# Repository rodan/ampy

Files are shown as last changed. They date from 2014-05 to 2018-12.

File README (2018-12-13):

an audio amplifier project that contains a mixer controlled by an MSP430 microcontroller

contents:
 hardware/power_amp  - power circuit for the amplifier
 hardware/power_pre  - power circuit used by the mixer board
 hardware/amp        - 2x25W amplifier. for a quad setup this board is used twice, for 6 channels it's used 3 times.
 hardware/mixer      - mixer board. 10 inputs, 6 outputs, 12 channels of mixing. a stereo-to-quad panning circuit is included

 firmware_mixer      - software that runs on the MSP430F5510 that is present on the mixer board
 firmware_brain      - software for the main uC (CC430F5137) that interfaces the user with the mixer board. currently user input comes via remote control presses.
 firmware_display    - software that runs on the atmega present on the BADGEr. this is a simple adaptation on Jeremy Blum's "Pi BADGEr ePaper Weather Station".

 linux               - linux client that talks over a serial link to firmware_brain and controls the mixer and the power amp

pictures now available: https://photos.app.goo.gl/L8txqSKrcZFV2BbR8

--------------------------------------------

Mixer board input

two different input methods are available, either via UART or I2C. since they use the exact same 2 pins the switch between them is a compile time option - see config.h. the i2c interface is highly recommended.

I2C implementation

the communication protocol consists of either a direct 14 byte read in which case the current settings are being shared, 2 byte writes for sending commands or 4 byte writes for sending new volume values. the slave address is 0x28.

UART commands
v___   set volume
 ||+ volume - [0-255]
 |+- channel - {r,l,b}
 +-- pga ID - [1-6]
     1: front, 2: rear, 3: line-in
     4: spdif, 5: front-rear pan, 6: center and subwoofer
m_     mute pga
 +- pga ID - [1-6]
u_     unmute pga
 +- pga ID - [1-6]
w_     write current settings to flash
 +- location [1-3]
r_     load saved settings from flash
 +- location [1-3]
s      show settings
?      show help

 homepage:        https://github.com/rodan/ampy
 author:          Petre Rodan <2b4eda@subdimension.ro>
 license:         GNU GPLv3

 parts of the code were originally forked from the openchronos-ng project [1]. 
 linux mixer control code based on alsamixer [2]

 software requirements:

   msp430 toolchain

[1] http://openchronos-ng.sourceforge.net
[2] http://www.alsa-project.org

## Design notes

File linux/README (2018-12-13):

Linux mixer control software for the ampy ecosystem.

Either an FTDI-based USB-to-uart or a USB bluetooth connection that supports SPP is used to connect to firmare_brain in order to control the mixer and the power amp boards.

All the PGA2311 chips present on the mixer board can be set in the [mixer view] and on the [amp view] the sound detection and mute signals can be toggled.
The second only works if the power amp is based on the LM4780 IC.

in order to compile, rnu the following:

./bootstrap
./configure
make

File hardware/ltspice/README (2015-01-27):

LTspice IV ver 4.22q simulations for the mixer board and the sound detection circuit

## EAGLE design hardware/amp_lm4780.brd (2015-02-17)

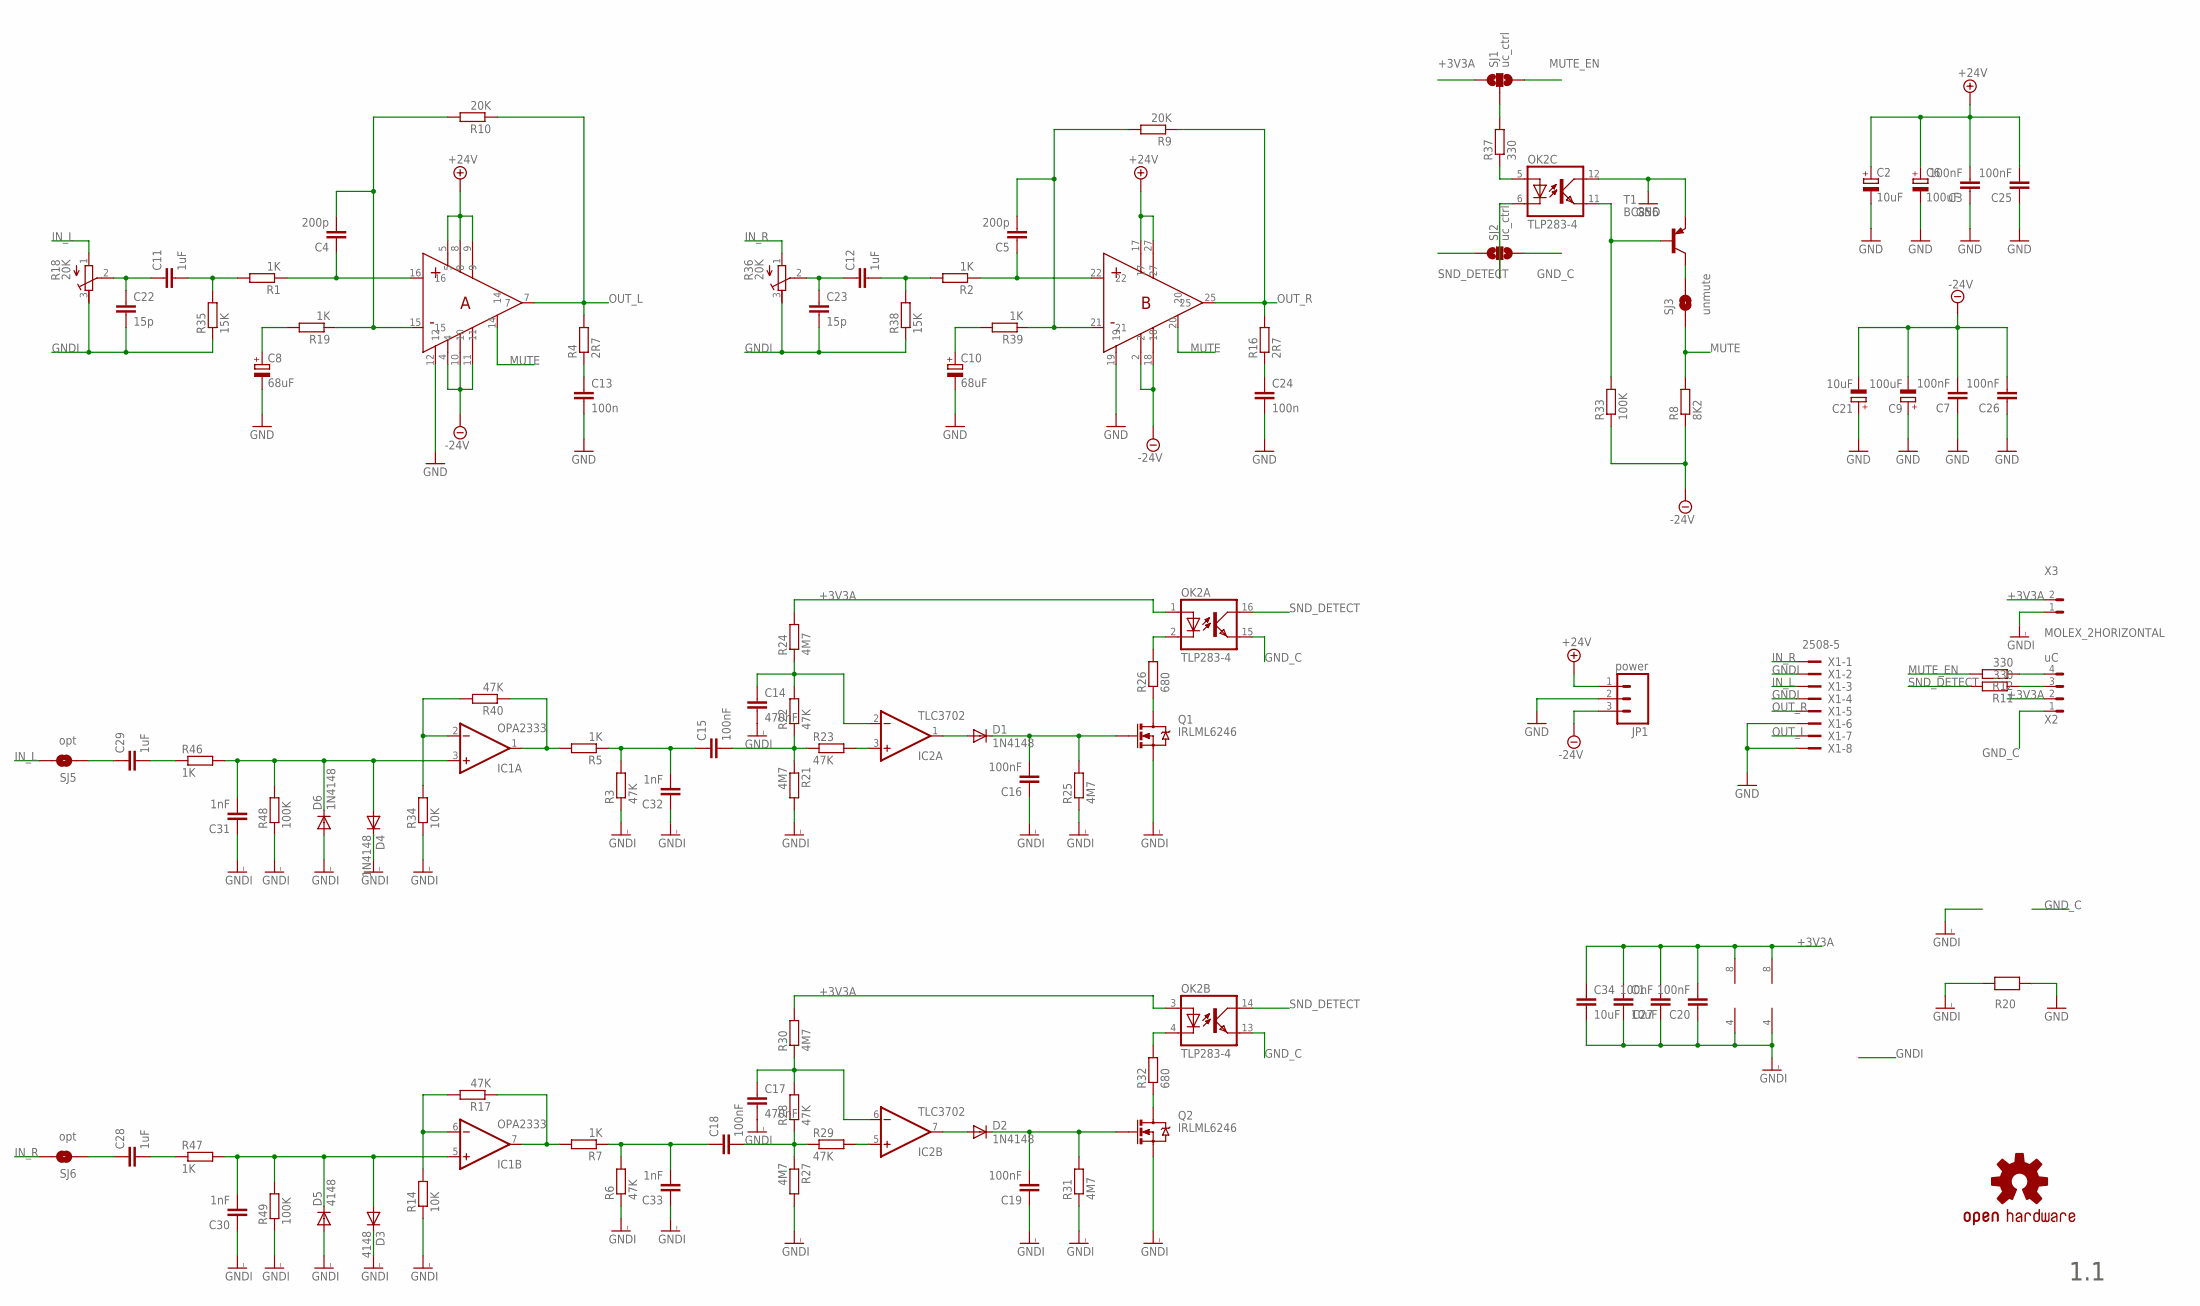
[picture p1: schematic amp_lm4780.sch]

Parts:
C1, C34: 10uF; C1206K
C2, C21: 10uF; PANASONIC_C
C3, C7, C15, C16, C18, C19, C20, C25, C26, C27: 100nF; C0805
C4, C5: 200p; C0805
C6, C9: 100uF; PANASONIC_G
C8, C10: 68uF; PANASONIC_E
C11, C12: 1uF; C050-035X075
C13, C24: 100n; C10B5
C14, C17: 470nF; C0805
C22, C23: 15p; C0805
C28, C29: 1uF; C0805
C30, C31, C32, C33: 1nF; C0805
D1, D2, D4, D6: 1N4148; SOD-123_MINI-SMA
D3, D5: 4148; SOD-123_MINI-SMA
IC1: OPA2333; SO08
IC2: TLC3702; SO08
JP1: power; 1X03
OK2: TLP283-4; MINI-FLAT-16
Q1, Q2: IRLML6246; SOT23-3
R1, R2, R5, R7, R46, R47: 1K; R0805W
R3, R6, R17, R22, R23, R28, R29, R40: 47K; R0805W
R4, R16: 2R7; P0613/15
R8: 8K2; R0805W
R9, R10: 20K; R0805W
R11, R12, R37: 330; R0805W
R14, R34: 10K; R0805W
R18, R36: 20K; RTRIM3339P
R19, R39: 1K; P0613/15
R20: 0R_0805; R0805W
R21, R24, R25, R27, R30, R31: 4M7; R0805W
R26, R32: 680; R0805W
R33, R48, R49: 100K; R0805W
R35, R38: 15K; R0805W
SJ1, SJ2: uc_ctrl; SJ_3_PASTE2&3
SJ3: unmute; SJ_2S-TRACE
SJ5, SJ6: opt; SJ_2S-TRACE
T1: BC856; SOT23-BEC
U$1: LM4780_H; TO220-27_HOR
U$7: OSHW-LOGOM; OSHW-LOGO-M
X1: 2508-5; PAK100/2500-5-08
X2: uC; 0530480401
X3: MOLEX_2HORIZONTAL; 0530480210

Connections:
+3V3A: C1.1, C20.2, C27.2, C34.1, IC1.8 (V+), IC2.8 (V+), OK2.1 (A), OK2.3 (A), R24.2, R30.2, SJ1.1, X2.2 (3), X3.2 (1)
+24V: C2.+, C3.2, C6.+, C25.2, JP1.1, U$1.5, U$1.8, U$1.9, U$1.17, U$1.27
-24V: C7.2, C9.-, C21.-, C26.2, JP1.3, R8.1, R33.1, U$1.2, U$1.4, U$1.10, U$1.11, U$1.18
GND: C2.-, C3.1, C6.-, C7.1, C8.-, C9.+, C10.-, C13.2, C21.+, C24.2, C25.1, C26.1, JP1.2, OK2.12 (COL), R20.2, T1.E, U$1.12, U$1.19, X1.6, X1.8
GNDI: C1.2, C14.2, C16.1, C17.2, C19.1, C20.1, C22.2, C23.2, C27.1, C30.1, C31.1, C32.1, C33.1, C34.2, D3.C, D4.C, D5.A, D6.A, IC1.4 (V-), IC2.4 (V-), Q1.2 (S), Q2.2 (S), R3.1, R6.1, R14.1, R18.3 (E), R20.1, R21.2, R25.1, R27.2, R31.1, R34.1, R35.1, R36.3 (E), R38.1, R48.1, R49.1, X1.2, X1.4, X3.1 (2)
GND_C: OK2.13 (EMIT), OK2.15 (EMIT), SJ2.3, X2.1 (4)
IN_L: R18.1 (A), SJ5.2, X1.3
IN_R: R36.1 (A), SJ6.2, X1.1
MUTE: R8.2, SJ3.1, U$1.14, U$1.20
MUTE_EN: R12.2, SJ1.3
unnamed: C5.2, R9.2, R39.1, U$1.21
unnamed: SJ3.2, T1.C
unnamed: R11.1, X2.3 (2)
unnamed: R12.1, X2.4 (1)
unnamed: IC1.6 (-IN), R14.2, R17.2
unnamed: C13.1, R4.1
unnamed: IC1.7 (OUT), R7.2, R17.1
unnamed: C4.1, R1.1, U$1.16
unnamed: C11.2, R1.2, R35.2
unnamed: C11.1, C22.1, R18.2 (S)
unnamed: C15.2, R21.1, R22.1, R23.1
unnamed: IC1.2 (-IN), R34.2, R40.2
unnamed: IC1.1 (OUT), R5.2, R40.1
unnamed: C24.1, R16.1
unnamed: D1.A, IC2.1 (OUT)
unnamed: C28.1, SJ6.1
unnamed: C30.2, D3.A, D5.C, IC1.5 (+IN), R47.2, R49.2
unnamed: C28.2, R47.1
unnamed: C29.1, SJ5.1
unnamed: IC2.3 (+IN), R23.2
unnamed: OK2.6 (C), SJ2.2
unnamed: Q1.3 (D), R26.1
unnamed: C14.1, IC2.2 (-IN), R22.2, R24.1
unnamed: C29.2, R46.1
unnamed: OK2.2 (C), R26.2
unnamed: C15.1, C32.2, R3.2, R5.1
unnamed: C31.2, D4.A, D6.C, IC1.3 (+IN), R46.2, R48.2
unnamed: C16.2, D1.C, Q1.1 (G), R25.2
unnamed: D2.A, IC2.7 (OUT)
unnamed: R37.2, SJ1.2
unnamed: C17.1, IC2.6 (-IN), R28.2, R30.1
unnamed: C18.2, R27.1, R28.1, R29.1
unnamed: C18.1, C33.2, R6.2, R7.1
unnamed: IC2.5 (+IN), R29.2
unnamed: C19.2, D2.C, Q2.1 (G), R31.2
unnamed: Q2.3 (D), R32.1
unnamed: OK2.4 (C), R32.2
unnamed: OK2.11 (EMIT), R33.2, T1.B
unnamed: C5.1, R2.1, U$1.22
unnamed: OK2.5 (A), R37.1
unnamed: C12.2, R2.2, R38.2
unnamed: C12.1, C23.1, R36.2 (S)
unnamed: C4.2, R10.2, R19.1, U$1.15
unnamed: C8.+, R19.2
unnamed: C10.+, R39.2
OUT_L: R4.2, R10.1, U$1.7, X1.7
OUT_R: R9.1, R16.2, U$1.25, X1.5
SND_DETECT: OK2.14 (COL), OK2.16 (COL), R11.2, SJ2.1

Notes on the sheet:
1.1

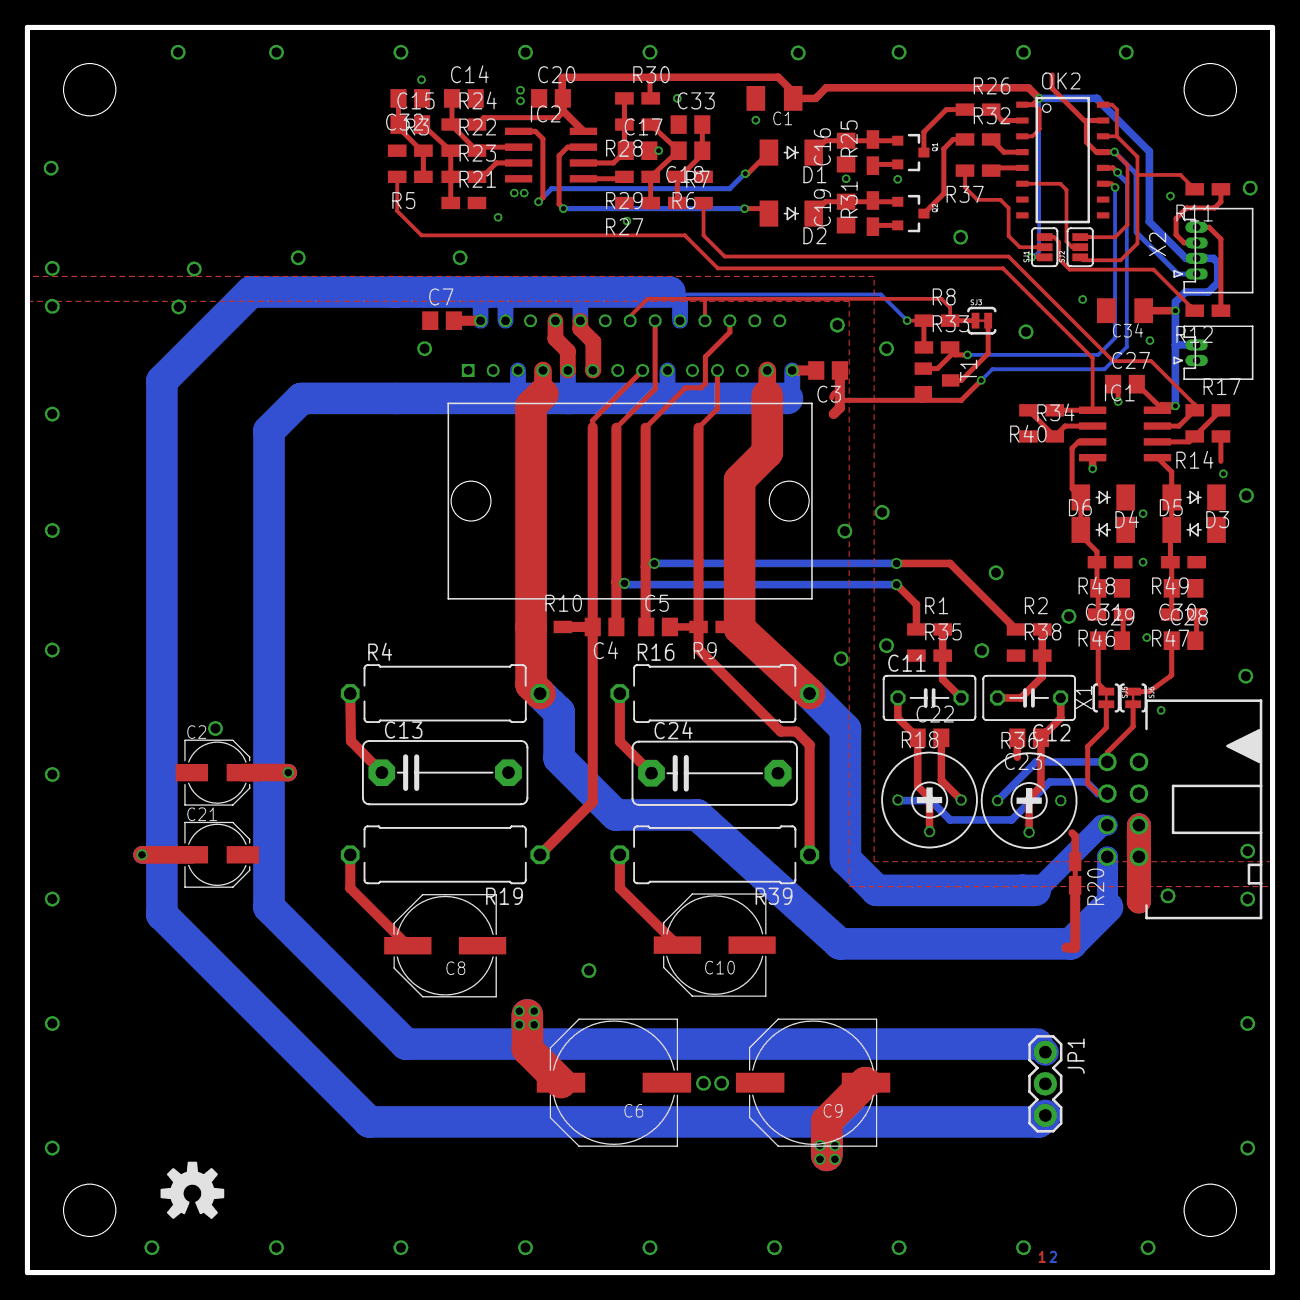
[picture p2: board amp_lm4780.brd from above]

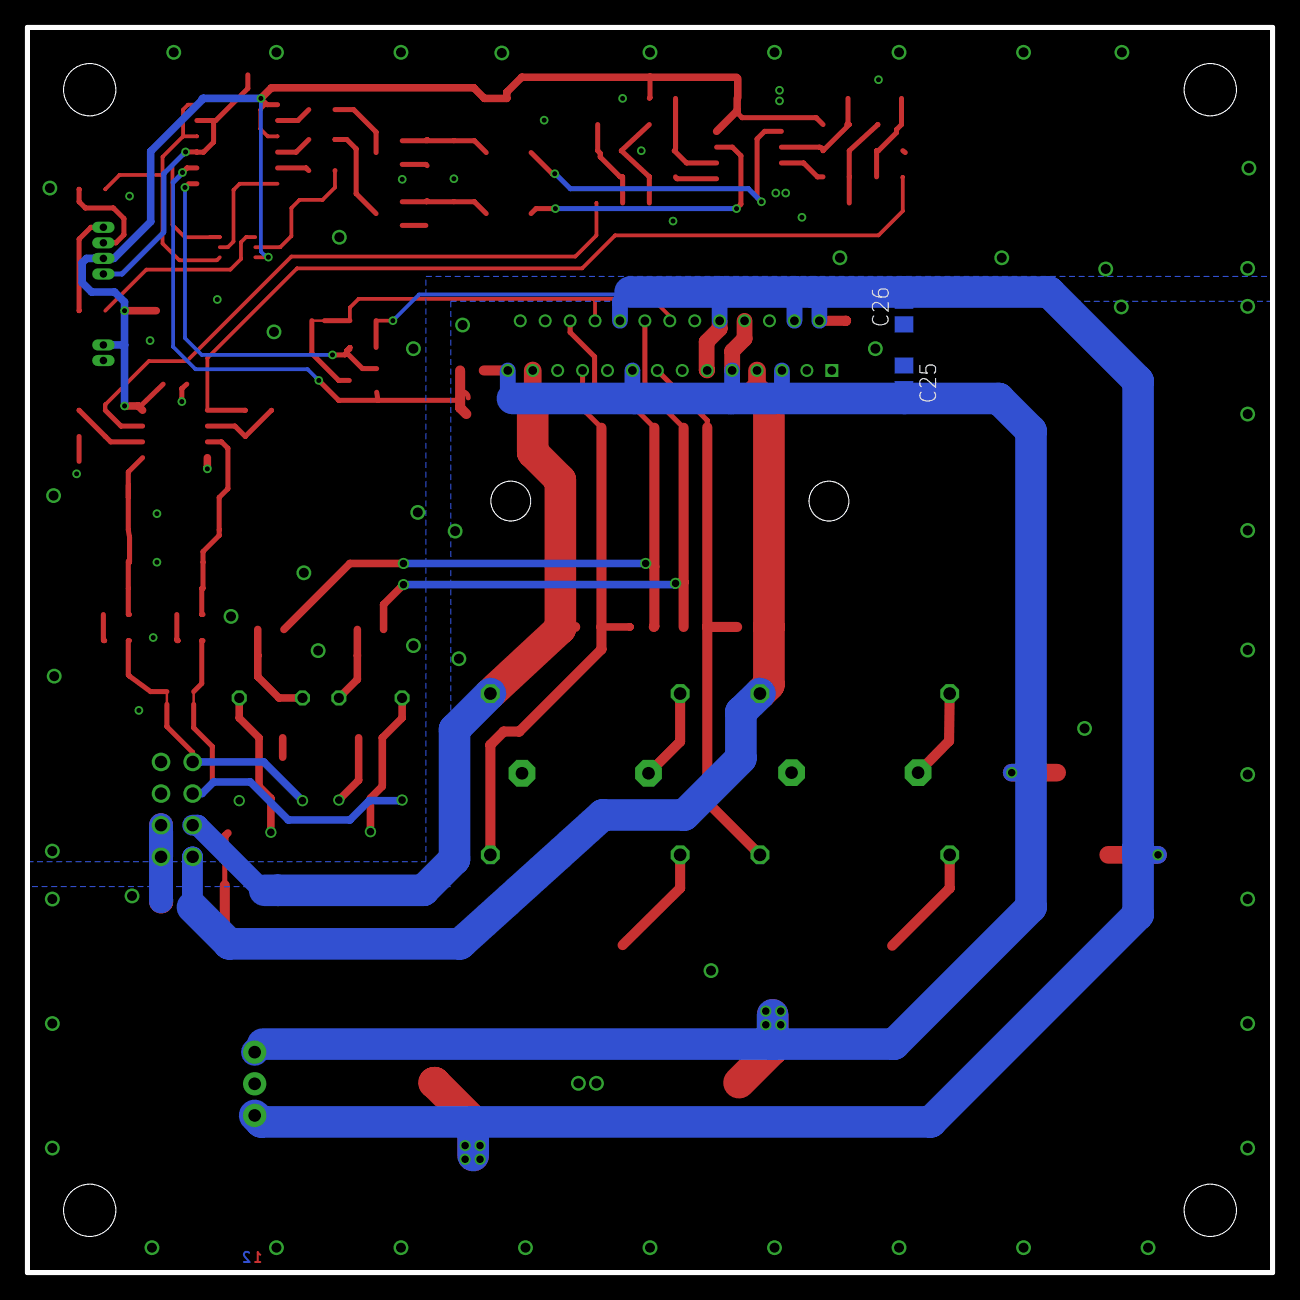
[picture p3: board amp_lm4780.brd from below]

Board: 4 copper layers, 100.0 x 100.0 mm, 99 parts (2 on the bottom side), 58 nets.

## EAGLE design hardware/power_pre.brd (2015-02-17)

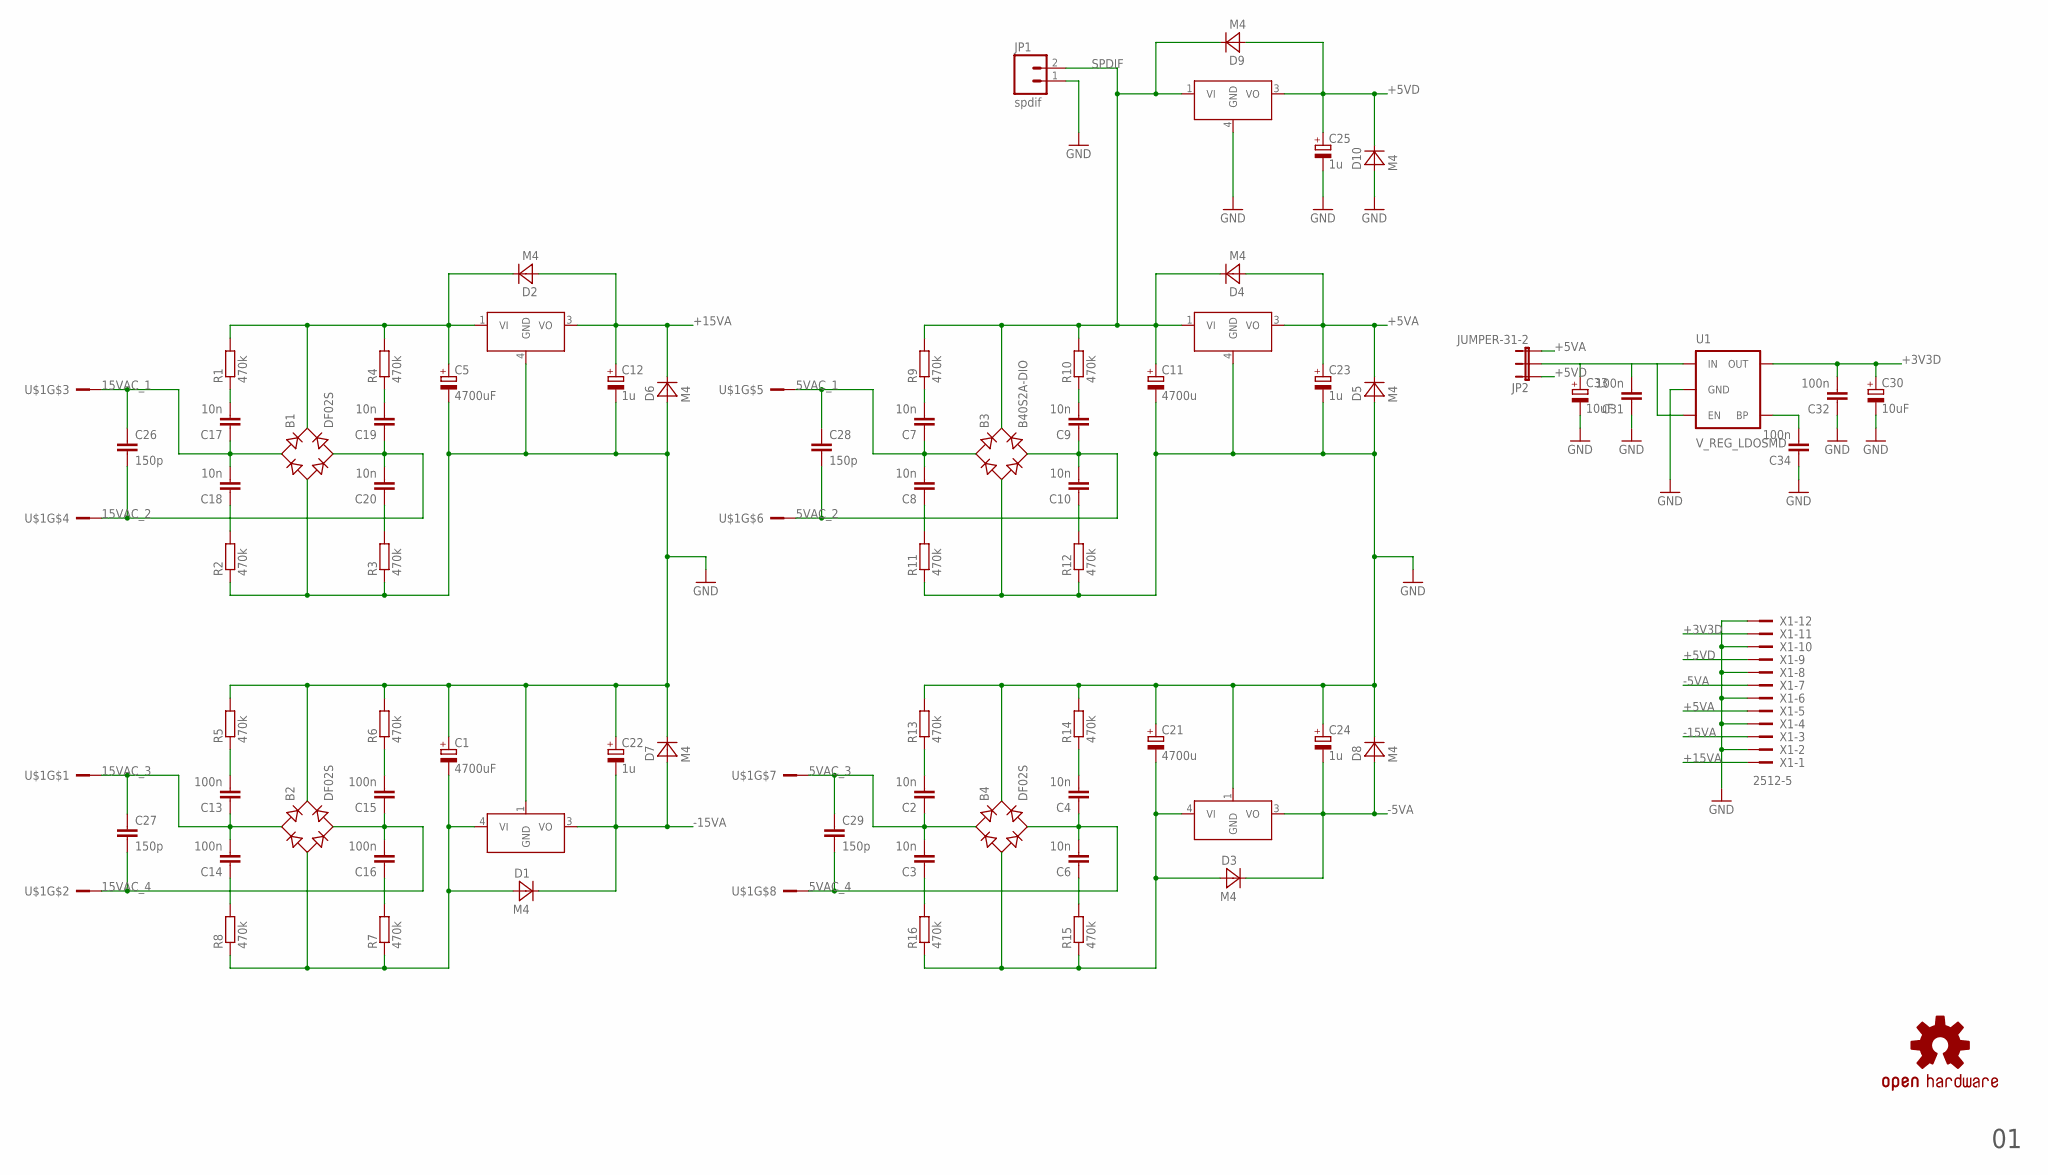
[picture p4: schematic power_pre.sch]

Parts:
B1, B2, B4: DF02S; DFS
B3: B40S2A-DIO; DFS
C1, C5: 4700uF; E7,5-18
C2, C3, C4, C6, C7, C8, C9, C10, C17, C18, C19, C20: 10n; C0805
C11, C21: 4700u; E7,5-16
C12, C22, C23, C24, C25: 1u; PANASONIC_B
C13, C14, C15, C16, C31, C32, C34: 100n; C0805
C26, C27, C28, C29: 150p; C5B4.5
C30, C33: 10uF; 153CLV-0405
D1, D2, D3, D4, D5, D6, D7, D8, D9, D10: M4; SMA
IC1: 7815; D2PACK
IC2: 7915; D2PACK
IC3, IC5: 7805; D2PACK
IC4: 7905; D2PACK
JP1: spdif; 1X02
JP2: JUMPER-31-2; SJ_3_PASTE1&2
R1, R2, R3, R4, R5, R6, R7, R8, R9, R10, R11, R12, R13, R14, R15, R16: 470k; R0805W
U1: V_REG_LDOSMD; SOT23-5
U$1: DEGSON_8
U$7: OSHW-LOGOM; OSHW-LOGO-M
X1: 2512-5; PAK100/2500-5-12

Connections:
5VAC_1: B3.AC1, C7.1, C8.2, C28.1, U$1.5
5VAC_2: B3.AC2, C9.1, C10.2, C28.2, U$1.6
5VAC_3: B4.AC1, C2.1, C3.2, C29.1, U$1.7
5VAC_4: B4.AC2, C4.1, C6.2, C29.2, U$1.8
15VAC_1: B1.AC1, C17.1, C18.2, C26.1, U$1.3
15VAC_2: B1.AC2, C19.1, C20.2, C26.2, U$1.4
15VAC_3: B2.AC1, C13.1, C14.2, C27.1, U$1.1
15VAC_4: B2.AC2, C15.1, C16.2, C27.2, U$1.2
+3V3D: C30.+, C32.2, U1.5 (OUT), X1.11
+5VA: C23.+, D4.A, D5.C, IC3.3 (VO), JP2.3, X1.5
+5VD: C25.+, D9.A, D10.C, IC5.3 (VO), JP2.1, X1.9
+15VA: C12.+, D2.A, D6.C, IC1.3 (VO), X1.1
-5VA: C24.-, D3.C, D8.A, IC4.3 (VO), X1.7
-15VA: C22.-, D1.C, D7.A, IC2.3 (VO), X1.3
GND: B1.-, B2.+, B3.-, B4.+, C1.+, C5.-, C11.-, C12.-, C21.+, C22.+, C23.-, C24.+, C25.-, C30.-, C31.1, C32.1, C33.-, C34.1, D5.A, D6.A, D7.C, D8.C, D10.A, IC1.4 (GND), IC2.1 (GND), IC3.4 (GND), IC4.1 (GND), IC5.4 (GND), JP1.1, R2.1, R3.1, R5.2, R6.2, R11.1, R12.1, R13.2, R14.2, U1.2 (GND), X1.2, X1.4, X1.6, X1.8, X1.10, X1.12
unnamed: C7.2, R9.1
unnamed: C18.1, R2.2
unnamed: C31.2, C33.+, JP2.2, U1.1 (IN), U1.3 (EN)
unnamed: C13.2, R5.1
unnamed: C34.2, U1.4 (BP)
unnamed: B1.+, C5.+, D2.C, IC1.1 (VI), R1.2, R4.2
unnamed: C17.2, R1.1
unnamed: B4.-, C21.-, D3.A, IC4.4 (VI), R15.1, R16.1
unnamed: C19.2, R4.1
unnamed: C20.1, R3.2
unnamed: C6.1, R15.2
unnamed: C8.1, R11.2
unnamed: B2.-, C1.-, D1.A, IC2.4 (VI), R7.1, R8.1
unnamed: C14.1, R8.2
unnamed: C16.1, R7.2
unnamed: C15.2, R6.1
unnamed: C10.1, R12.2
unnamed: C9.2, R10.1
unnamed: C3.1, R16.2
unnamed: C2.2, R13.1
unnamed: C4.2, R14.1
SPDIF: B3.+, C11.+, D4.C, D9.C, IC3.1 (VI), IC5.1 (VI), JP1.2, R9.2, R10.2

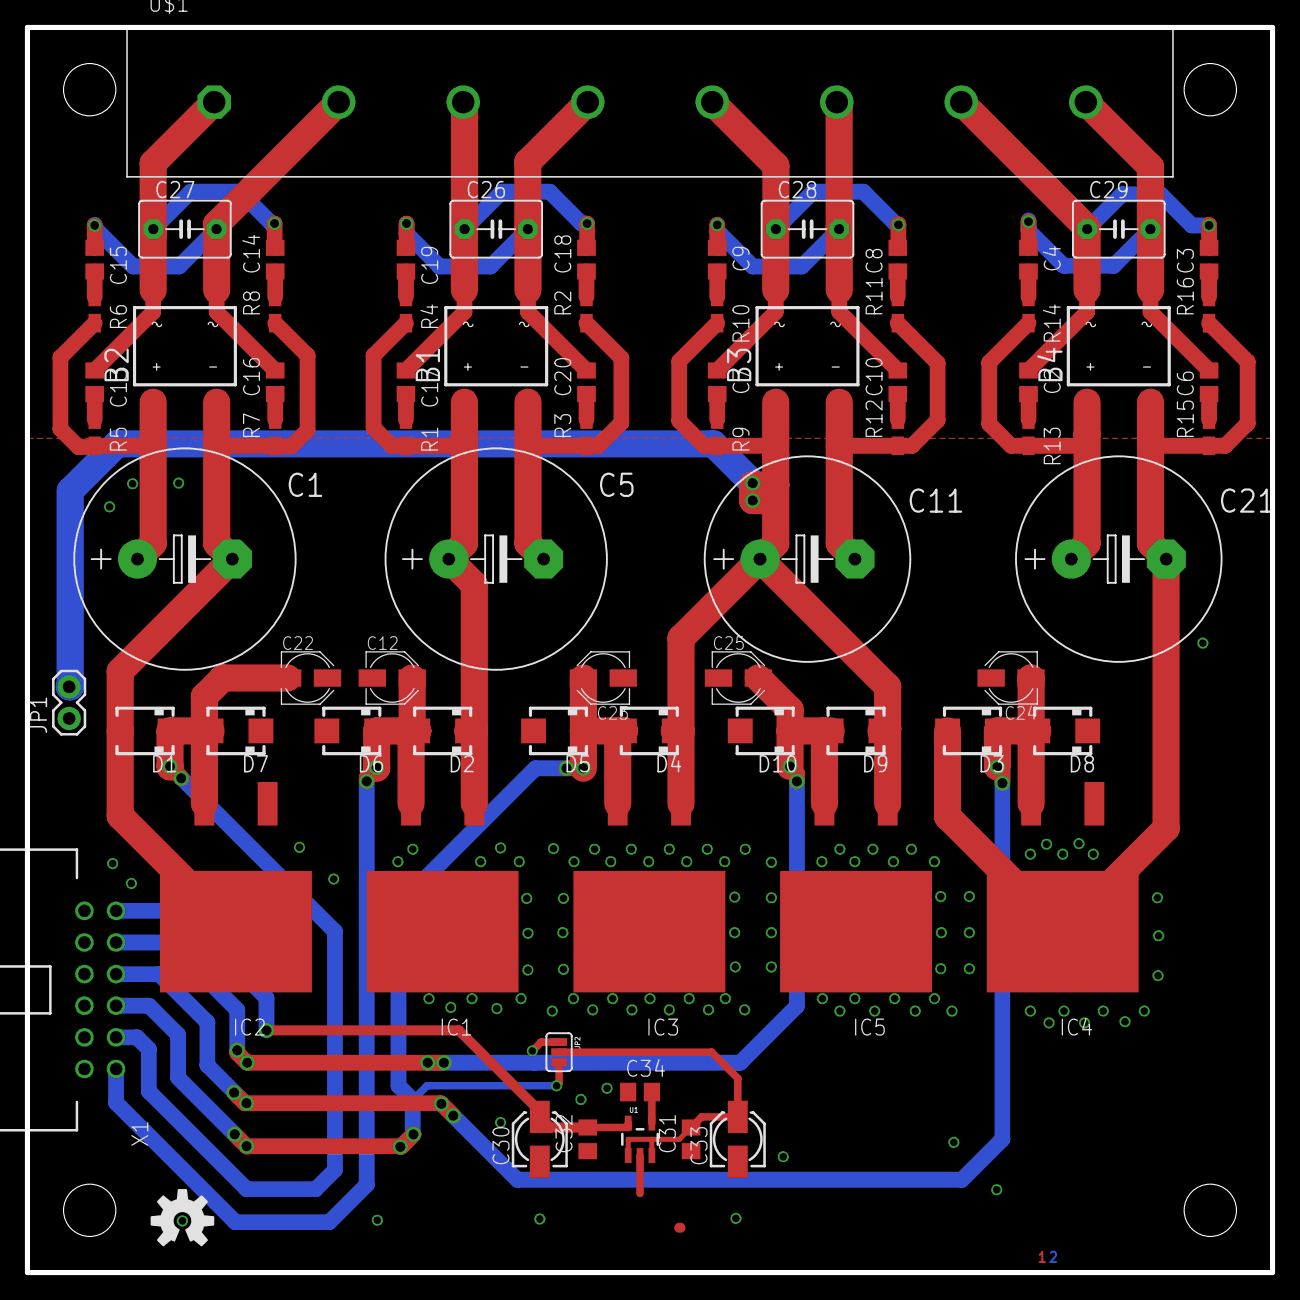
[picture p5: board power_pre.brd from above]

Board: 4 copper layers, 100.0 x 100.0 mm, 75 parts (0 on the bottom side), 37 nets.

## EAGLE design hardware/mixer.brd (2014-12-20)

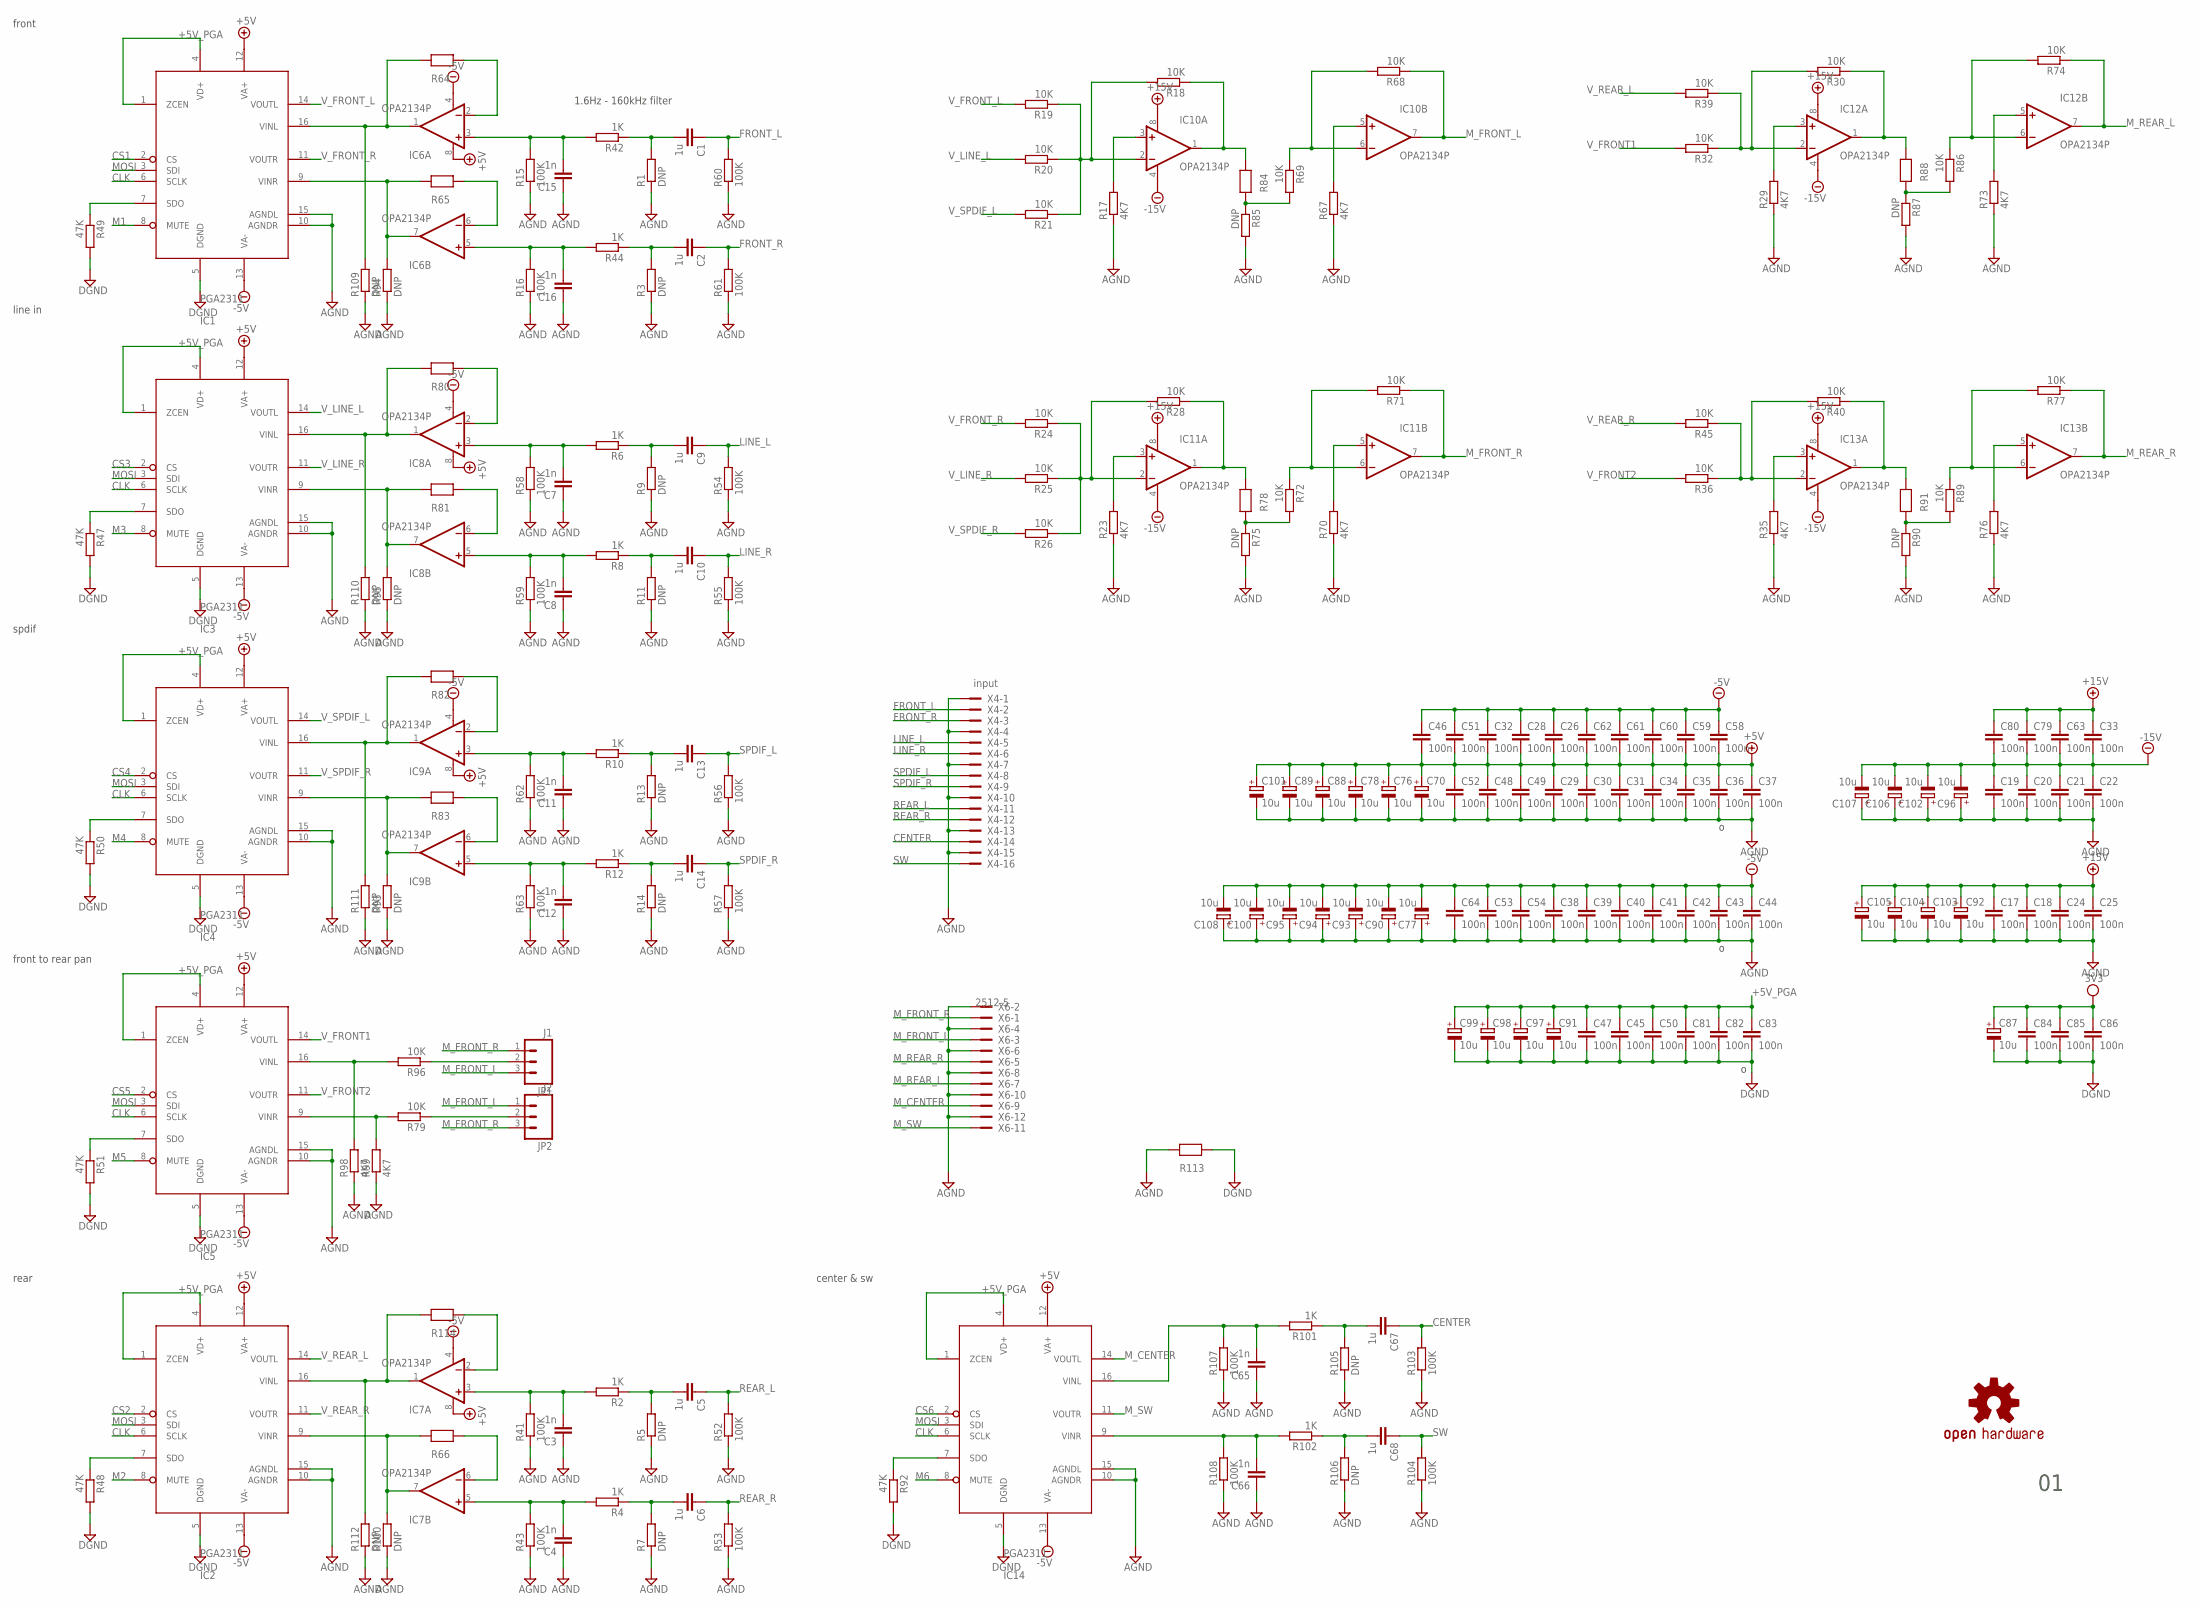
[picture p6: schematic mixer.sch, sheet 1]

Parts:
C1, C2, C5, C6, C9, C10, C13, C14, C67, C68: 1u; C0805
C3, C4, C7, C8, C11, C12, C15, C16, C65, C66: 1n; C0805
C17, C18, C19, C20, C21, C22, C24, C25, C26, C28, C29, C30, C31, C32, C33, C34, C35, C36, C37, C38, C39, C40, C41, C42, C43, C44, C45, C46, C47, C48, C49, C50, C51, C52, C53, C54, C58, C59, C60, C61, C62, C63, C64, C79, C80, C81, C82, C83, C84, C85, C86: 100n; C0805
C70, C76, C77, C78, C87, C88, C89, C90, C91, C92, C93, C94, C95, C96, C97, C98, C99, C100, C101, C102, C103, C104, C105, C106, C107, C108: 10u; 153CLV-0405
IC1, IC2, IC3, IC4, IC5, IC14: PGA2311; SO-16
IC6, IC7, IC8, IC9, IC10, IC11, IC12, IC13: OPA2134P; DIL08
JP1: J1; 1X03
JP2: J2; 1X03
R1, R3, R5, R7, R9, R11, R13, R14, R75, R85, R87, R90, R93, R94, R95, R100, R105, R106, R109, R110, R111, R112: DNP; R0805W
R2, R4, R6, R8, R10, R12, R42, R44, R101, R102: 1K; R0805W
R15, R16, R41, R43, R52, R53, R54, R55, R56, R57, R58, R59, R60, R61, R62, R63, R103, R104, R107, R108: 100K; R0805W
R17, R23, R29, R35, R67, R70, R73, R76, R98, R99: 4K7; R0805W
R18, R19, R20, R21, R24, R25, R26, R28, R30, R32, R36, R39, R40, R45, R68, R69, R71, R72, R74, R77, R79, R86, R89, R96: 10K; R0805W
R47, R48, R49, R50, R51, R92: 47K; R0805W
R64, R65, R66, R78, R80, R81, R82, R83, R84, R88, R91, R113, R114: 0R_0805; R0805W
U$7: OSHW-LOGOM; OSHW-LOGO-M
X4: input; PAK100/2500-5-16
X6: 2512-5; PAK100/2500-5-12

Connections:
3V3: C84.1, C85.1, C86.1, C87.+; also elsewhere on the board
+5V: C26.2, C28.2, C29.1, C30.1, C31.1, C32.2, C34.1, C35.1, C36.1, C37.1, C46.2, C48.1, C49.1, C51.2, C52.1, C58.2, C59.2, C60.2, C61.2, C62.2, C70.+, C76.+, C78.+, C88.+, C89.+, C101.+, IC1.12 (VA+), IC2.12 (VA+), IC3.12 (VA+), IC4.12 (VA+), IC5.12 (VA+), IC6.8 (V+), IC7.8 (V+), IC8.8 (V+), IC9.8 (V+), IC14.12 (VA+); also elsewhere on the board
+5V_PGA: C45.1, C47.1, C50.1, C81.1, C82.1, C83.1, C91.+, C97.+, C98.+, C99.+, IC1.1 (ZCEN), IC1.4 (VD+), IC2.1 (ZCEN), IC2.4 (VD+), IC3.1 (ZCEN), IC3.4 (VD+), IC4.1 (ZCEN), IC4.4 (VD+), IC5.1 (ZCEN), IC5.4 (VD+), IC14.1 (ZCEN), IC14.4 (VD+); also elsewhere on the board
+15V: C17.1, C18.1, C24.1, C25.1, C33.1, C63.1, C79.1, C80.1, C92.+, C103.+, C104.+, C105.+, IC10.8 (V+), IC11.8 (V+), IC12.8 (V+), IC13.8 (V+); also elsewhere on the board
-5V: C26.1, C28.1, C32.1, C38.1, C39.1, C40.1, C41.1, C42.1, C43.1, C44.1, C46.1, C51.1, C53.1, C54.1, C58.1, C59.1, C60.1, C61.1, C62.1, C64.1, C77.-, C90.-, C93.-, C94.-, C95.-, C100.-, C108.-, IC1.13 (VA-), IC2.13 (VA-), IC3.13 (VA-), IC4.13 (VA-), IC5.13 (VA-), IC6.4 (V-), IC7.4 (V-), IC8.4 (V-), IC9.4 (V-), IC14.13 (VA-); also elsewhere on the board
-15V: C19.1, C20.1, C21.1, C22.1, C33.2, C63.2, C79.2, C80.2, C96.-, C102.-, C106.-, C107.-, IC10.4 (V-), IC11.4 (V-), IC12.4 (V-), IC13.4 (V-); also elsewhere on the board
AGND: C3.1, C4.1, C7.1, C8.1, C11.1, C12.1, C15.1, C16.1, C17.2, C18.2, C19.2, C20.2, C21.2, C22.2, C24.2, C25.2, C29.2, C30.2, C31.2, C34.2, C35.2, C36.2, C37.2, C38.2, C39.2, C40.2, C41.2, C42.2, C43.2, C44.2, C48.2, C49.2, C52.2, C53.2, C54.2, C64.2, C65.1, C66.1, C70.-, C76.-, C77.+, C78.-, C88.-, C89.-, C90.+, C92.-, C93.+, C94.+, C95.+, C96.+, C100.+, C101.-, C102.+, C103.-, C104.-, C105.-, C106.+, C107.+, C108.+, IC1.10 (AGNDR), IC1.15 (AGNDL), IC2.10 (AGNDR), IC2.15 (AGNDL), IC3.10 (AGNDR), IC3.15 (AGNDL), IC4.10 (AGNDR), IC4.15 (AGNDL), IC5.10 (AGNDR), IC5.15 (AGNDL), IC14.10 (AGNDR), IC14.15 (AGNDL), R1.1, R3.1, R5.1, R7.1, R9.1, R11.1, R13.1, R14.1, R15.1, R16.1, R17.1, R23.1, R29.1, R35.1, R41.1, R43.1, R52.1, R53.1, R54.1, R55.1, R56.1, R57.1, R58.1, R59.1, R60.1, R61.1, R62.1, R63.1, R67.1, R70.1, R73.1, R75.2, R76.1, R85.2, R87.2, R90.2, R93.1, R94.1, R95.1, R98.1, R99.1, R100.1, R103.1, R104.1, R105.1, R106.1, R107.1, R108.1, R109.1, R110.1, R111.1, R112.1, R113.1, X4.1, X4.4, X4.7, X4.10, X4.13, X4.15, X6.2, X6.4, X6.6, X6.8, X6.10, X6.12; also elsewhere on the board
CENTER: C67.1, R103.2, X4.14
CLK: IC1.6 (SCLK), IC2.6 (SCLK), IC3.6 (SCLK), IC4.6 (SCLK), IC5.6 (SCLK), IC14.6 (SCLK); also elsewhere on the board
CS1: IC1.2 (CS); also elsewhere on the board
CS2: IC2.2 (CS); also elsewhere on the board
CS3: IC3.2 (CS); also elsewhere on the board
CS4: IC4.2 (CS); also elsewhere on the board
CS5: IC5.2 (CS); also elsewhere on the board
CS6: IC14.2 (CS); also elsewhere on the board
DGND: C45.2, C47.2, C50.2, C81.2, C82.2, C83.2, C84.2, C85.2, C86.2, C87.-, C91.-, C97.-, C98.-, C99.-, IC1.5 (DGND), IC2.5 (DGND), IC3.5 (DGND), IC4.5 (DGND), IC5.5 (DGND), IC14.5 (DGND), R47.2, R48.2, R49.2, R50.2, R51.2, R92.2, R113.2; also elsewhere on the board
FRONT_L: C1.1, R60.2, X4.2
FRONT_R: C2.1, R61.2, X4.3
LINE_L: C9.1, R54.2, X4.5
LINE_R: C10.1, R55.2, X4.6
M1: IC1.8 (MUTE); also elsewhere on the board
M2: IC2.8 (MUTE); also elsewhere on the board
M3: IC3.8 (MUTE); also elsewhere on the board
M4: IC4.8 (MUTE); also elsewhere on the board
M5: IC5.8 (MUTE); also elsewhere on the board
M6: IC14.8 (MUTE); also elsewhere on the board
MOSI: IC1.3 (SDI), IC2.3 (SDI), IC3.3 (SDI), IC4.3 (SDI), IC5.3 (SDI), IC14.3 (SDI); also elsewhere on the board
M_CENTER: IC14.14 (VOUTL), X6.9
M_FRONT_L: IC10.7 (OUT), JP1.3, JP2.1, R68.1, X6.3
M_FRONT_R: IC11.7 (OUT), JP1.1, JP2.3, R71.1, X6.1
M_REAR_L: IC12.7 (OUT), R74.1, X6.7
M_REAR_R: IC13.7 (OUT), R77.1, X6.5
M_SW: IC14.11 (VOUTR), X6.11
unnamed: C1.2, R1.2, R42.1
unnamed: C2.2, R3.2, R44.1
unnamed: IC14.7 (SDO), R92.1
unnamed: IC2.16 (VINL), IC7.1 (OUT), R112.2, R114.1
unnamed: IC1.16 (VINL), IC6.1 (OUT), R64.1, R109.2
unnamed: IC2.9 (VINR), IC7.7 (OUT), R66.1, R100.2
unnamed: C4.2, IC7.5 (+IN), R4.2, R43.2
unnamed: C3.2, IC7.3 (+IN), R2.2, R41.2
unnamed: C5.2, R2.1, R5.2
unnamed: C6.2, R4.1, R7.2
unnamed: IC3.16 (VINL), IC8.1 (OUT), R80.1, R110.2
unnamed: IC3.9 (VINR), IC8.7 (OUT), R81.1, R95.2
unnamed: IC1.9 (VINR), IC6.7 (OUT), R65.1, R94.2
unnamed: C8.2, IC8.5 (+IN), R8.2, R59.2
unnamed: IC4.16 (VINL), IC9.1 (OUT), R82.1, R111.2
unnamed: C7.2, IC8.3 (+IN), R6.2, R58.2
unnamed: C9.2, R6.1, R9.2
unnamed: C10.2, R8.1, R11.2
unnamed: C65.2, IC14.16 (VINL), R101.2, R107.2
unnamed: IC4.9 (VINR), IC9.7 (OUT), R83.1, R93.2
unnamed: C12.2, IC9.5 (+IN), R12.2, R63.2
unnamed: C11.2, IC9.3 (+IN), R10.2, R62.2
unnamed: C16.2, IC6.5 (+IN), R16.2, R44.2
unnamed: C13.2, R10.1, R13.2
unnamed: C14.2, R12.1, R14.2
unnamed: C15.2, IC6.3 (+IN), R15.2, R42.2
unnamed: C66.2, IC14.9 (VINR), R102.2, R108.2
unnamed: JP1.2, R96.1
unnamed: IC6.2 (-IN), R64.2
unnamed: IC5.16 (VINL), R96.2, R98.2
unnamed: IC6.6 (-IN), R65.2
unnamed: IC1.7 (SDO), R49.1
unnamed: IC3.7 (SDO), R47.1
unnamed: IC10.3 (+IN), R17.2
unnamed: IC10.2 (-IN), R18.2, R19.1, R20.1, R21.1
unnamed: IC7.2 (-IN), R114.2
unnamed: IC10.1 (OUT), R18.1, R84.2
unnamed: IC7.6 (-IN), R66.2
unnamed: IC13.2 (-IN), R36.1, R40.2, R45.1
unnamed: IC11.3 (+IN), R23.2
unnamed: IC11.2 (-IN), R24.1, R25.1, R26.1, R28.2
unnamed: IC10.5 (+IN), R67.2
unnamed: IC10.6 (-IN), R68.2, R69.1
unnamed: IC8.2 (-IN), R80.2
unnamed: IC2.7 (SDO), R48.1
unnamed: IC12.3 (+IN), R29.2
unnamed: IC4.7 (SDO), R50.1
unnamed: IC11.5 (+IN), R70.2
unnamed: C67.2, R101.1, R105.2
unnamed: C68.2, R102.1, R106.2
unnamed: IC13.3 (+IN), R35.2
unnamed: IC5.7 (SDO), R51.1
unnamed: IC11.6 (-IN), R71.2, R72.1
unnamed: IC8.6 (-IN), R81.2
unnamed: IC12.5 (+IN), R73.2
unnamed: IC12.6 (-IN), R74.2, R86.1
unnamed: IC9.2 (-IN), R82.2
unnamed: IC13.5 (+IN), R76.2
unnamed: IC13.6 (-IN), R77.2, R89.1
unnamed: IC9.6 (-IN), R83.2
unnamed: IC12.2 (-IN), R30.2, R32.1, R39.1
unnamed: IC11.1 (OUT), R28.1, R78.2
unnamed: IC12.1 (OUT), R30.1, R88.2
unnamed: R69.2, R84.1, R85.1
unnamed: IC13.1 (OUT), R40.1, R91.2
unnamed: IC5.9 (VINR), R79.2, R99.2
unnamed: JP2.2, R79.1
unnamed: R72.2, R75.1, R78.1
unnamed: R86.2, R87.1, R88.1
unnamed: R89.2, R90.1, R91.1
REAR_L: C5.1, R52.2, X4.11
REAR_R: C6.1, R53.2, X4.12
SPDIF_L: C13.1, R56.2, X4.8
SPDIF_R: C14.1, R57.2, X4.9
SW: C68.1, R104.2, X4.16
V_FRONT1: IC5.14 (VOUTL), R32.2
V_FRONT2: IC5.11 (VOUTR), R36.2
V_FRONT_L: IC1.14 (VOUTL), R19.2
V_FRONT_R: IC1.11 (VOUTR), R24.2
V_LINE_L: IC3.14 (VOUTL), R20.2
V_LINE_R: IC3.11 (VOUTR), R25.2
V_REAR_L: IC2.14 (VOUTL), R39.2
V_REAR_R: IC2.11 (VOUTR), R45.2
V_SPDIF_L: IC4.14 (VOUTL), R21.2
V_SPDIF_R: IC4.11 (VOUTR), R26.2

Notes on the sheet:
rear
line in
spdif
front to rear pan
front
1.6Hz - 160kHz filter
center & sw

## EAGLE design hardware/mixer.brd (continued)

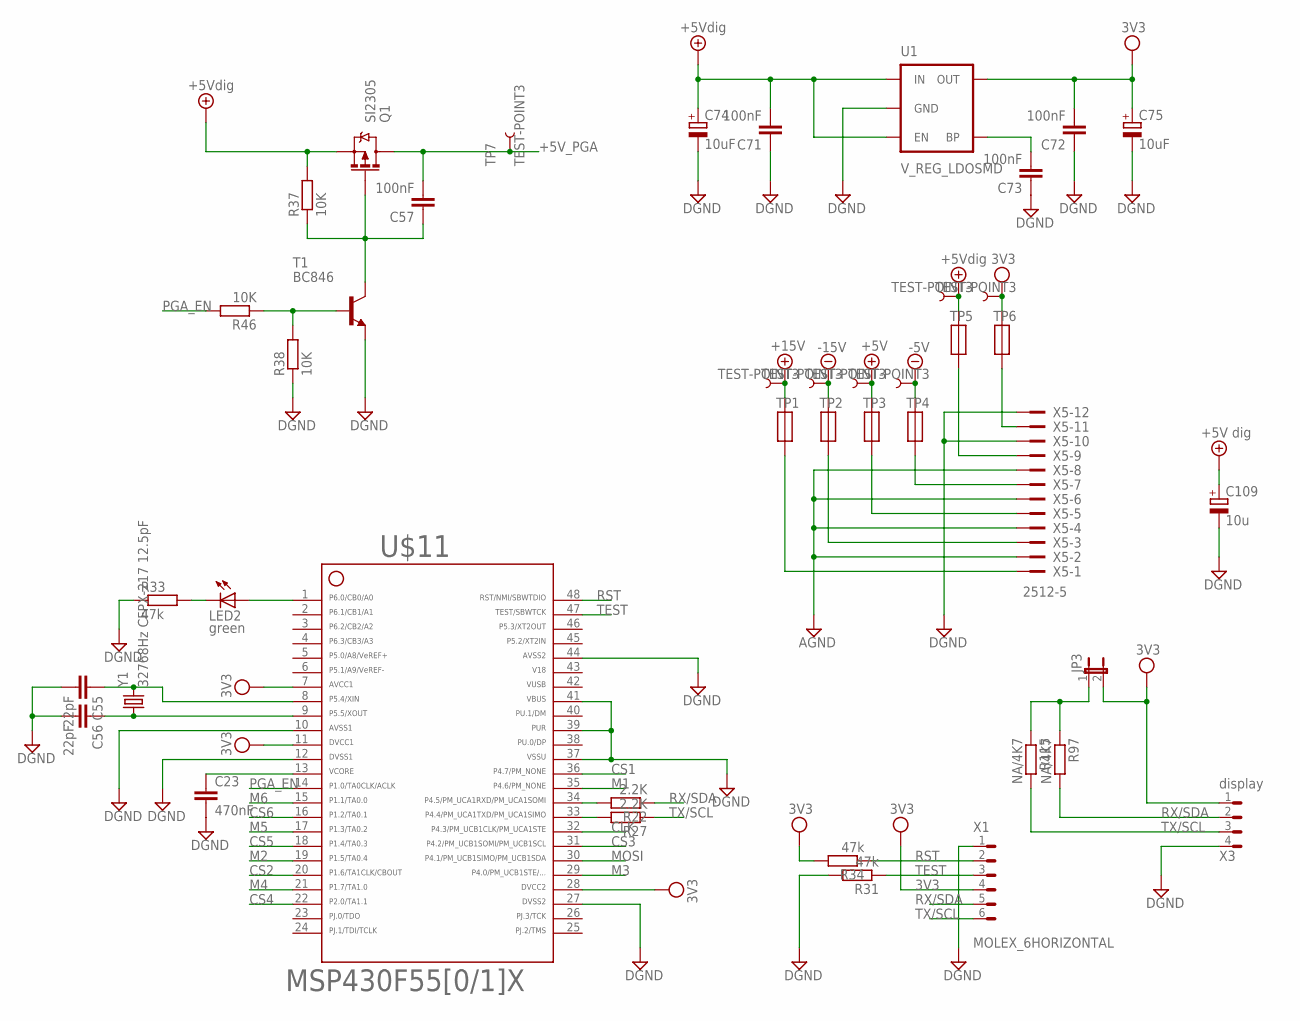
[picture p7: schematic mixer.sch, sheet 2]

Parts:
C23: 470nF; C0805
C55, C56: 22pF; C0805
C57, C71, C72, C73: 100nF; C0805
C74, C75: 10uF; 153CLV-0405
C109: 10u; 153CLV-0405
JP3: JUMPER-2SMD-NO; SJ_2S-NO
LED2: green; CHIPLED_0805
Q1: SI2305; SOT23-3_POWER
R22, R27: 2.2K; R0805W
R31, R33, R34: 47k; R0805W
R37, R38, R46: 10K; R0805W
R97, R115: NA/4K7; R0805W
T1: BC846; SOT23
TP1, TP2, TP3, TP4, TP5, TP6, TP7: TEST-POINT3; PAD.03X.03
U1: V_REG_LDOSMD; SOT23-5
U$2, U$5, U$6, U$9, U$12, U$13: RESETTABLE; 1210
U$11: F55[0/1]X---PT48; PT48
X1: MOLEX_6HORIZONTAL; 0530480610
X3: display; 0530480401
X5: 2512-5; PAK100/2500-5-12
Y1: 32768Hz CFPX-217 12.5pF; CRYSTAL-SMD-3.2X1.5

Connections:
3V3: C72.2, C75.+, JP3.2, R34.2, TP6.P$1, U1.5 (OUT), U$11.7, U$11.11, U$11.28, U$13.P$2, X1.4, X3.1; also elsewhere on the board
42: U$11.42
43: U$11.43
46: U$11.46
+5V: TP3.P$1, U$6.P$2; also elsewhere on the board
+5V/1: C71.2, C74.+, C109.+, Q1.2 (S), R37.2, TP5.P$1, U1.1 (IN), U1.3 (EN), U$12.P$2
+5V_PGA: C57.2, Q1.3 (D), TP7.P$1; also elsewhere on the board
+15V: TP1.P$1, U$2.P$2; also elsewhere on the board
-5V: TP4.P$1, U$9.P$2; also elsewhere on the board
-15V: TP2.P$1, U$5.P$2; also elsewhere on the board
AGND: X5.2, X5.4, X5.6, X5.8; also elsewhere on the board
CLK: U$11.32; also elsewhere on the board
CS1: U$11.36; also elsewhere on the board
CS2: U$11.20; also elsewhere on the board
CS3: U$11.31; also elsewhere on the board
CS4: U$11.22; also elsewhere on the board
CS5: U$11.18; also elsewhere on the board
CS6: U$11.16; also elsewhere on the board
DGND: C23.2, C55.2, C56.2, C71.1, C72.1, C73.1, C74.-, C75.-, C109.-, R31.2, R33.1, R38.1, T1.2 (E), U1.2 (GND), U$11.10, U$11.12, U$11.27, U$11.37, U$11.39, U$11.41, U$11.44, X1.1, X3.4, X5.10, X5.12; also elsewhere on the board
M1: U$11.35; also elsewhere on the board
M2: U$11.19; also elsewhere on the board
M3: U$11.29; also elsewhere on the board
M4: U$11.21; also elsewhere on the board
M5: U$11.17; also elsewhere on the board
M6: U$11.15; also elsewhere on the board
MOSI: U$11.30; also elsewhere on the board
unnamed: LED2.A, U$11.1
unnamed: C23.1, U$11.13
unnamed: JP3.1, R97.1, R115.1
unnamed: C56.1, U$11.9, Y1.P$1 (1)
unnamed: C55.1, U$11.8, Y1.P$2 (2)
unnamed: LED2.C, R33.2
unnamed: C57.1, Q1.1 (G), R37.1, T1.3 (C)
unnamed: R38.2, R46.1, T1.1 (B)
unnamed: C73.2, U1.4 (BP)
unnamed: U$2.P$1, X5.1
unnamed: U$5.P$1, X5.3
unnamed: U$6.P$1, X5.5
unnamed: U$9.P$1, X5.7
unnamed: U$12.P$1, X5.9
unnamed: U$13.P$1, X5.11
P4.4: R27.2, U$11.33
P4.5: R22.2, U$11.34
PGA_EN: R46.2, U$11.14
RST: R34.1, U$11.48, X1.2
RX/SDA: R22.1, R97.2, X1.5, X3.2
TEST: R31.1, U$11.47, X1.3
TX/SCL: R27.1, R115.2, X1.6, X3.3

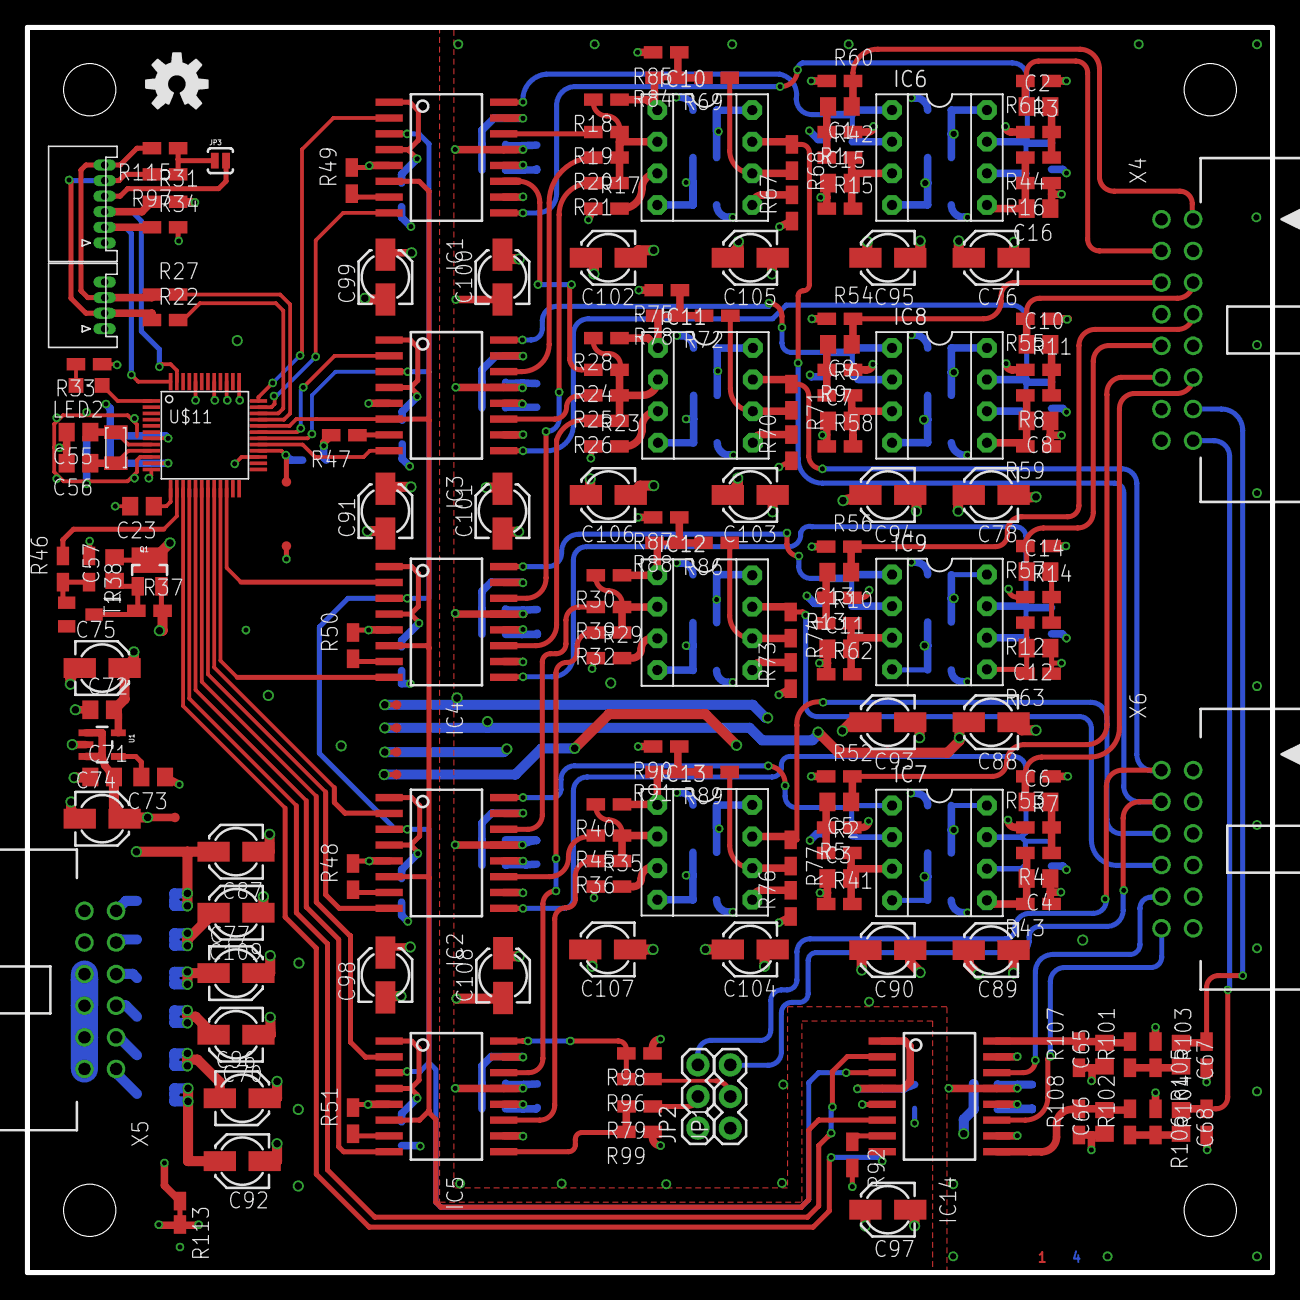
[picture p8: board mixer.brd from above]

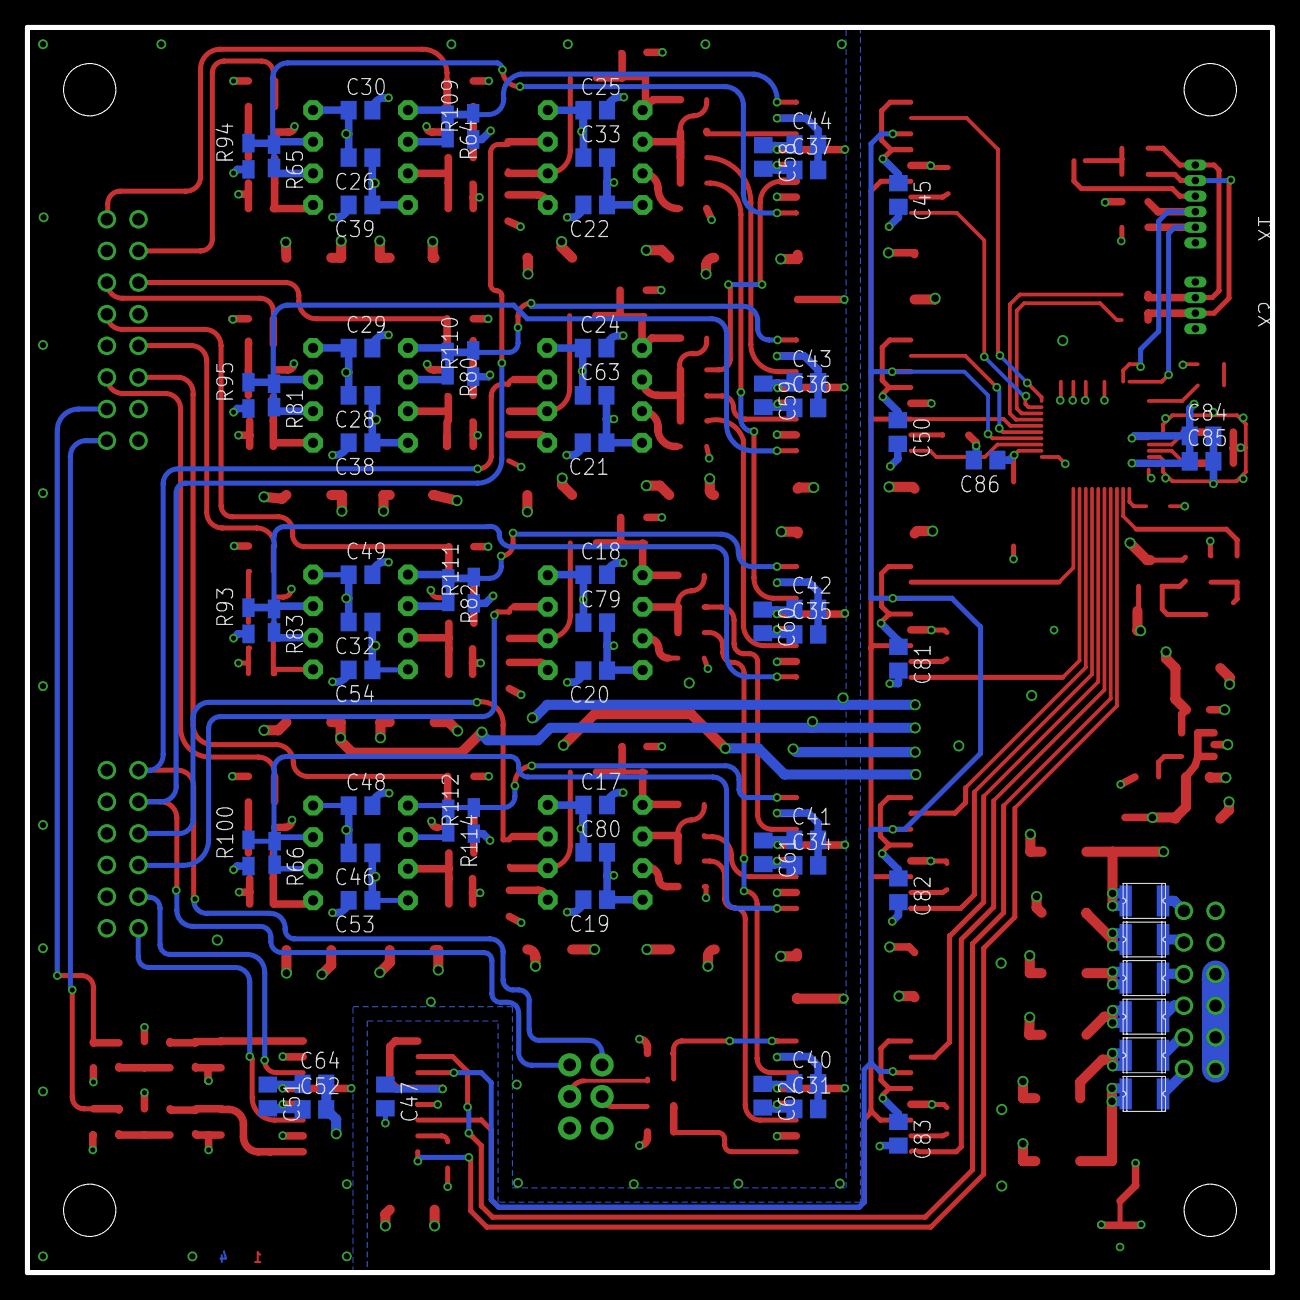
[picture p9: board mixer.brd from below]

Board: 4 copper layers, 100.0 x 100.0 mm, 264 parts (73 on the bottom side), 141 nets.

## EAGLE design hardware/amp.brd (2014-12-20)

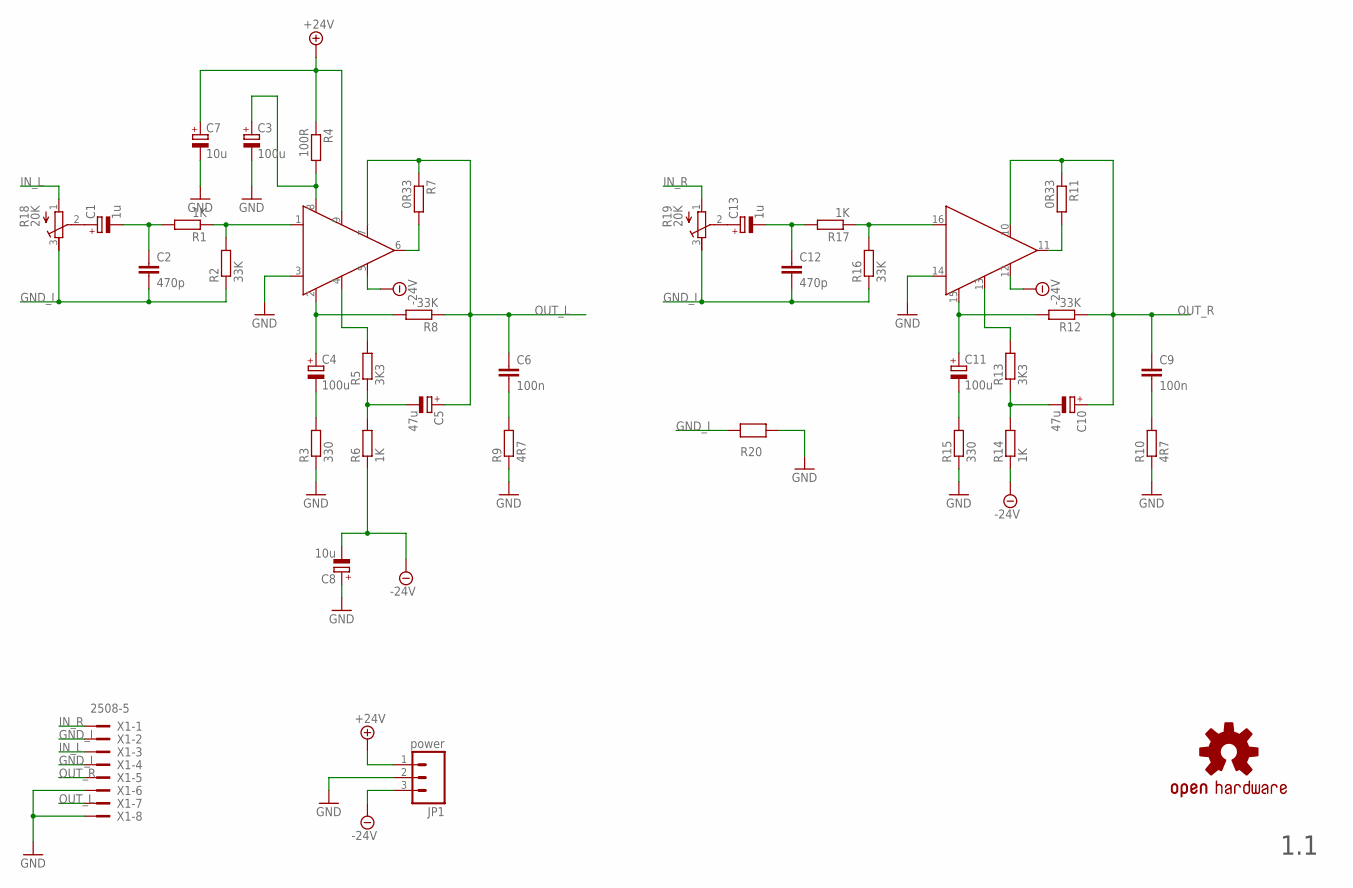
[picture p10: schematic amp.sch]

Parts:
C1, C13: 1u; PANASONIC_B
C2, C12: 470p; C0805
C3, C4, C11: 100u; PANASONIC_G
C5, C10: 47u; PANASONIC_F
C6, C9: 100n; C10B5
C7, C8: 10u; PANASONIC_D
JP1: power; 1X03
R1, R17: 1K; R0805W
R2, R16: 33K; R0805W
R3, R15: 330; P0613/15
R4: 100R; P0613/15
R5, R13: 3K3; P0613/15
R6, R14: 1K; P0613/15
R7, R11: 0R33; P0613/15
R8, R12: 33K; P0613/15
R9, R10: 4R7; P0613/15
R18, R19: 20K; RTRIM3339P
R20: 0R_0805; R0805W
U$1: STK465HORIZ-BOTTOM; STK465-HB
U$7: OSHW-LOGOM; OSHW-LOGO-M
X1: 2508-5; PAK100/2500-5-08

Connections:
+24V: C7.+, JP1.1, R4.1, U$1.9
-24V: C8.-, JP1.3, R6.1, R14.1, U$1.5, U$1.12
GND: C3.-, C7.-, C8.+, JP1.2, R3.1, R9.1, R10.1, R15.1, R20.2, U$1.3, U$1.14, X1.6, X1.8
GND_I: C2.2, C12.2, R2.1, R16.1, R18.3 (E), R19.3 (E), R20.1, X1.2, X1.4
IN_L: R18.1 (A), X1.3
IN_R: R19.1 (A), X1.1
unnamed: C4.-, R3.2
unnamed: C4.+, R8.2, U$1.2
unnamed: C5.-, R5.1, R6.2
unnamed: C6.2, R9.2
unnamed: R7.2, U$1.6
unnamed: C3.+, R4.2, U$1.8
unnamed: R5.2, U$1.4
unnamed: R1.1, R2.2, U$1.1
unnamed: C1.-, C2.1, R1.2
unnamed: C1.+, R18.2 (S)
unnamed: C13.+, R19.2 (S)
unnamed: R11.2, U$1.11
unnamed: C11.-, R15.2
unnamed: R16.2, R17.1, U$1.16
unnamed: C12.1, C13.-, R17.2
unnamed: C11.+, R12.2, U$1.15
unnamed: C10.-, R13.1, R14.2
unnamed: R13.2, U$1.13
unnamed: C9.2, R10.2
OUT_L: C5.+, C6.1, R7.1, R8.1, U$1.7, X1.7
OUT_R: C9.1, C10.+, R11.1, R12.1, U$1.10, X1.5

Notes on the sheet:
1.1

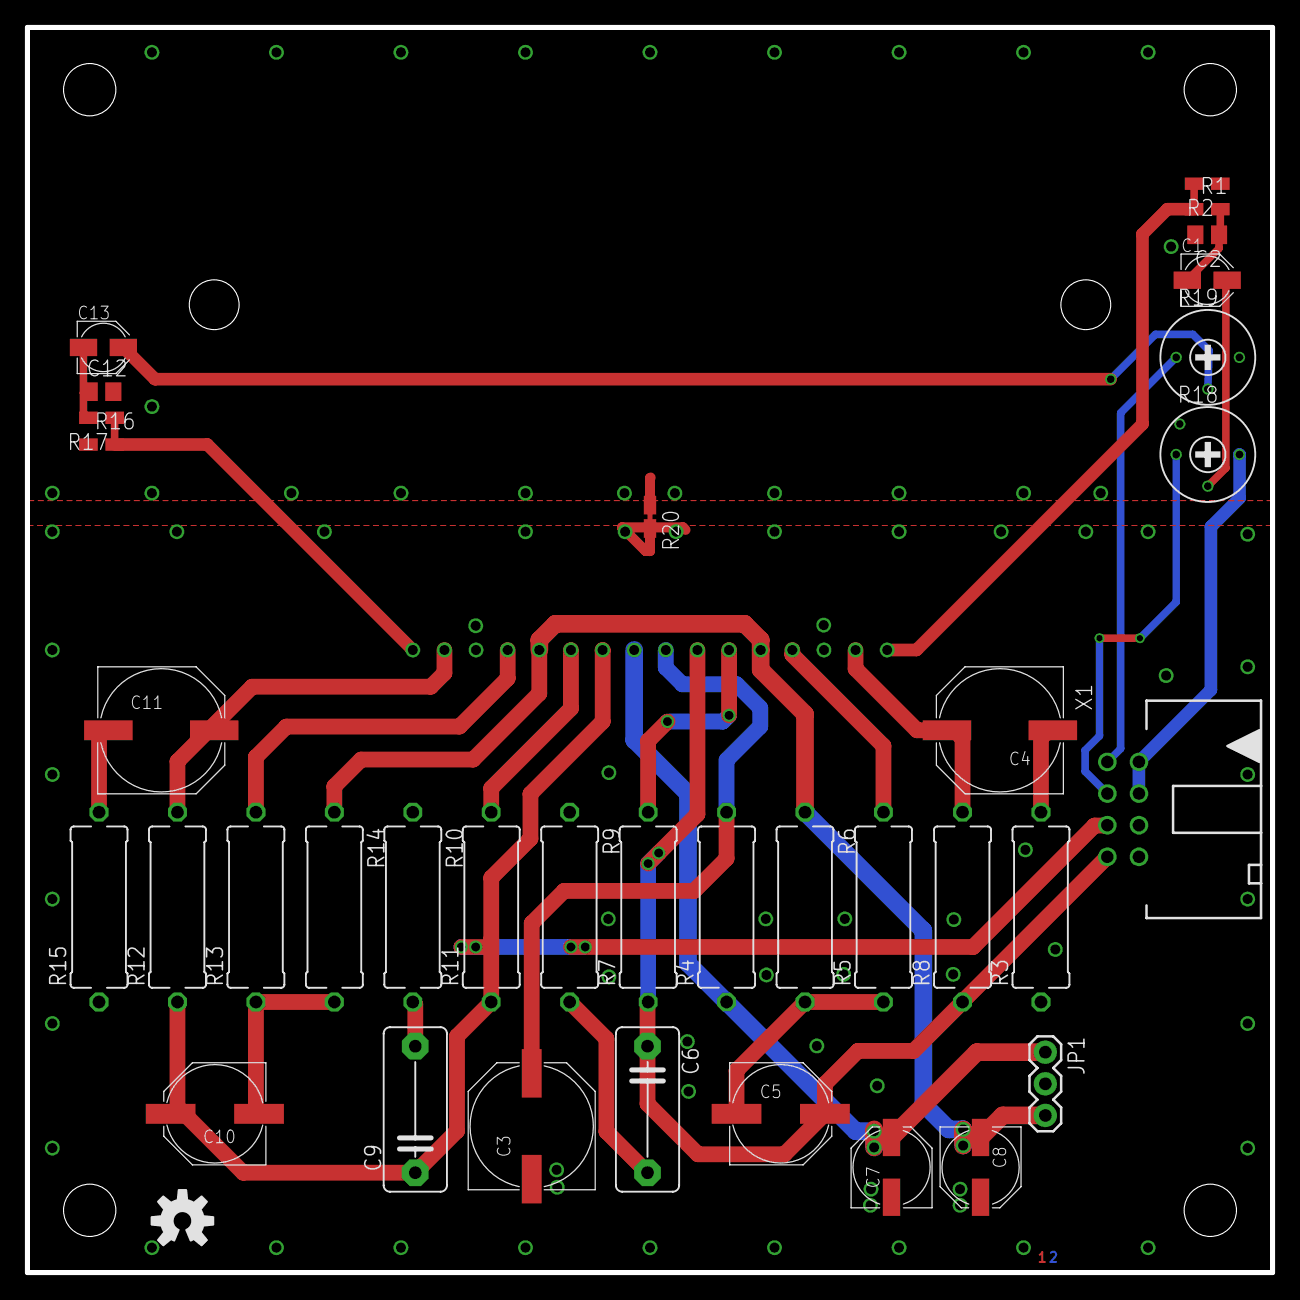
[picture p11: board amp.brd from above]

Board: 4 copper layers, 100.0 x 100.0 mm, 37 parts (0 on the bottom side), 27 nets.

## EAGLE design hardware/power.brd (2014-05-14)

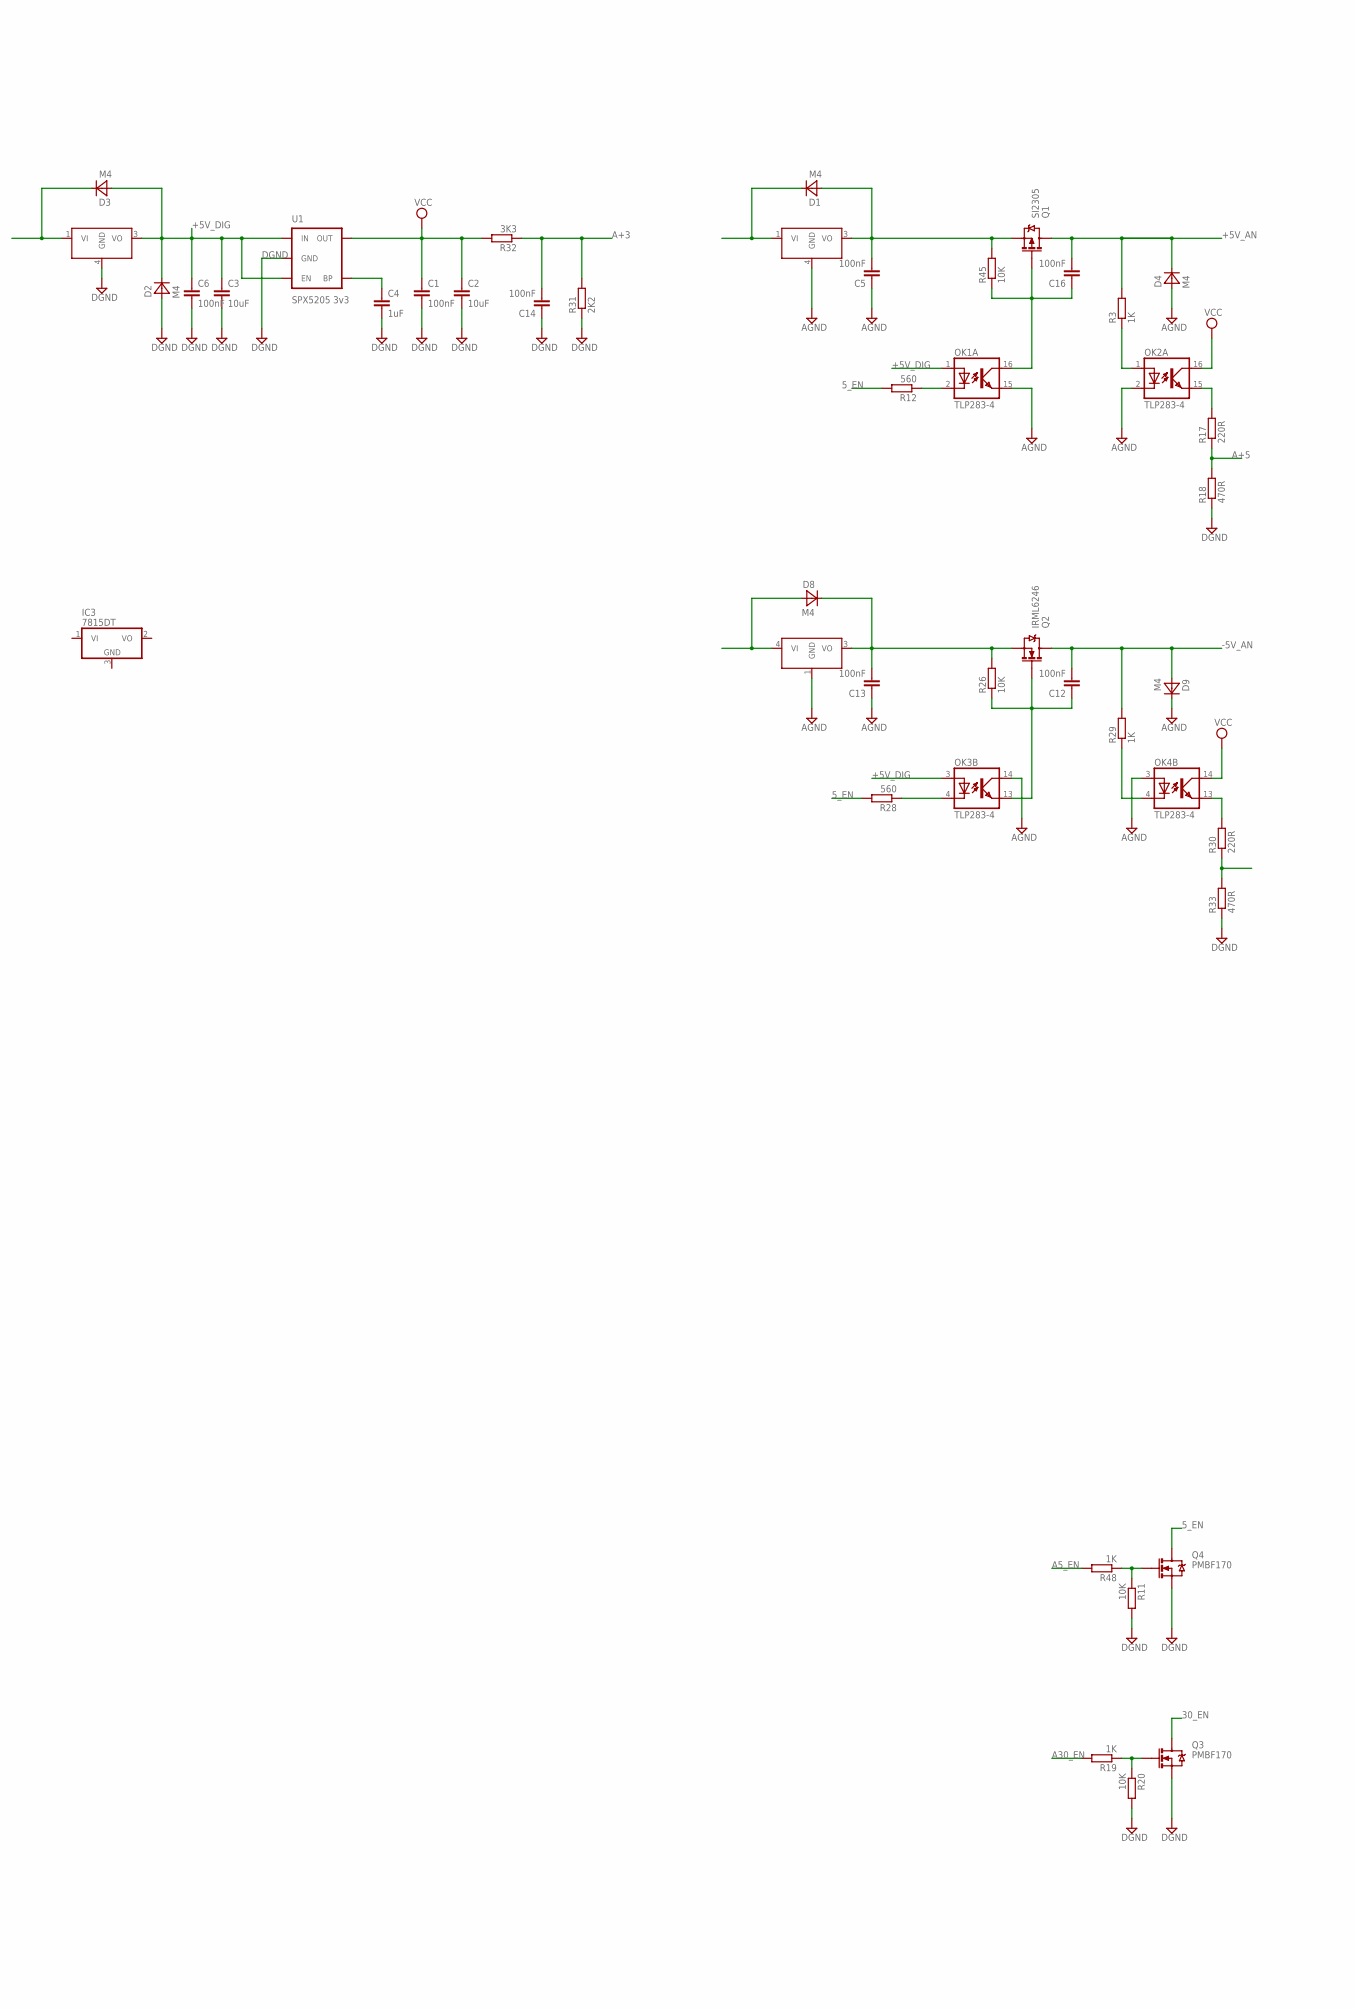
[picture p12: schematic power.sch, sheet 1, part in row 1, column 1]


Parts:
C1, C5, C6, C8, C9, C12, C13, C14, C16, C17, C19, C21: 100nF; C0805
C2, C3: 10uF; C1206
C4: 1uF; C0805
C10: 470nF; C0805
C23, C24: 22pF; C0805
D1, D2, D3, D4, D6, D7, D8, D9: M4; SMA
IC1, IC2: 7805; D2PACK
IC3: 7815DT; TO252
IC4: 7905; D2PACK
LED1: green; CHIP-LED0805
LED2: orange; CHIP-LED0805
OK1, OK2, OK3, OK4: TLP283-4; MINI-FLAT-16
Q1: SI2305; SOT23-3_POWER
Q2: IRML6246; SOT23-3_POWER
Q3, Q4: PMBF170; SOT23-3
Q7: IRFR5305; D-PAK_TO252AA
Q8: IRFR1205; D-PAK_TO252AA
R1, R2, R12, R28: 560; R0805W
R3, R10, R19, R27, R29, R48: 1K; R0805W
R4, R5, R6, R7: 4.7k; R0805W
R8, R14, R15, R16, R21: 0R; R0805W
R9, R13: 7.5K; R0805W
R11, R20, R26, R45, R49, R51: 10K; R0805W
R17, R22, R24, R30: 220R; R0805W
R18, R23, R25, R33: 470R; R0805W
R31: 2K2; R0805W
R32: 3K3; R0805W
R34, R35: 47k; R0805W
R50, R52: 33K; R0805W
U1: SPX5205 3v3; SOT23-5
U$1: F55[0/1]X---PT48; PT48
U$7: OSHW-LOGOM; OSHW-LOGO-M
X1: MOLEX_6VERTICAL; 0530470610
Y1: 32768Hz CFPX-217 12.5pF; CRYSTAL-SMD-3.2X1.5

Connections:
5_EN: Q4.3 (D), R12.2, R28.2
30_EN: Q3.3 (D), R1.2, R2.2
42: U$1.42
43: U$1.43
46: U$1.46
$N2: C13.2, D8.C, IC4.3 (VO), Q2.2 (S), R26.2
$N333: C5.2, D1.A, IC1.3 (VO), Q1.2 (S), R45.2
+5V_AN: C16.2, D4.C, Q1.3 (D), R3.2
+5V_DIG: C3.1, C6.1, D2.C, D3.A, IC2.3 (VO), OK1.1 (A), OK1.5 (A), OK1.7 (A), OK3.3 (A), U1.1 (IN), U1.3 (EN)
+30V: C19.2, D6.C, Q7.2 (D), R9.2
-5V_AN: C12.2, D9.A, Q2.3 (D), R29.2
-30V: C21.2, D7.A, Q8.2 (D), R13.2
A5_EN: R48.2
A30_EN: R19.2
A+3: C14.2, R31.2, R32.1, U$1.5
A+5: R17.1, R18.2, U$1.1
A+30: U$1.3
A-5: U$1.2
A-30: U$1.4
AGND: C5.1, C13.1, D4.A, D6.A, D7.C, D9.C, IC1.4 (GND), IC4.1 (GND), OK1.10 (COL), OK1.11 (EMIT), OK1.15 (EMIT), OK2.2 (C), OK2.6 (C), OK2.7 (A), OK3.14 (COL), OK4.3 (A), R8.2, R14.2, R15.2, R16.2, R21.2
DGND: C1.2, C2.2, C3.2, C4.2, C6.2, C14.1, D2.A, IC2.4 (GND), Q3.2 (S), Q4.2 (S), R8.1, R11.2, R14.1, R15.1, R16.1, R18.1, R20.2, R21.1, R23.1, R25.1, R31.1, R33.1, U1.2 (GND)
GND: C8.1, C9.1, C10.2, C17.1, C23.2, C24.2, LED1.C, R27.1, R35.2, U$1.10, U$1.12, U$1.27, U$1.37, U$1.39, U$1.41, U$1.44, X1.1
LED: R10.2, U$1.36
unnamed: LED1.A, R10.1
unnamed: C4.1, U1.4 (BP)
unnamed: D1.C, IC1.1 (VI)
unnamed: Q4.1 (G), R11.1, R48.1
unnamed: C10.1, U$1.13
unnamed: OK1.2 (C), R12.1
unnamed: OK1.8 (C), R2.1
unnamed: R6.2, U$1.34
unnamed: OK2.1 (A), R3.1
unnamed: R7.2, U$1.33
unnamed: OK2.5 (A), R9.1
unnamed: OK2.8 (C), R13.1
unnamed: Q3.1 (G), R19.1, R20.1
unnamed: OK1.6 (C), R1.1
unnamed: D3.C, IC2.1 (VI)
unnamed: OK2.15 (EMIT), R17.2
unnamed: C12.1, OK3.13 (EMIT), Q2.1 (G), R26.1
unnamed: C24.1, U$1.9, Y1.P$1 (1)
unnamed: C23.1, U$1.8, Y1.P$2 (2)
unnamed: OK2.11 (EMIT), R22.2
unnamed: R22.1, R23.2
unnamed: OK2.9 (EMIT), R24.2
unnamed: R24.1, R25.2
unnamed: D8.A, IC4.4 (VI)
unnamed: OK3.4 (C), R28.1
unnamed: OK4.4 (C), R29.1
unnamed: OK4.13 (EMIT), R30.2
unnamed: R30.1, R33.2
unnamed: C16.1, OK1.16 (COL), Q1.1 (G), R45.1
unnamed: LED2.C, R27.2
unnamed: Q7.3 (S), R49.2
unnamed: C19.1, Q7.1 (G), R49.1, R50.2
unnamed: OK1.12 (COL), R50.1
unnamed: Q8.3 (S), R51.2
unnamed: C21.1, Q8.1 (G), R51.1, R52.2
unnamed: OK1.9 (EMIT), R52.1
RST: R34.1, U$1.48, X1.2
RX: R6.1, X1.5
SCL: R4.2, U$1.31
SDA: R5.2, U$1.30
TEST: R35.1, U$1.47, X1.3
TX: R7.1, X1.6
VCC: C1.1, C2.1, C8.2, C9.2, C17.2, OK2.10 (COL), OK2.12 (COL), OK2.16 (COL), OK4.14 (COL), R4.1, R5.1, R32.2, R34.2, U1.5 (OUT), U$1.7, U$1.11, U$1.28, X1.4

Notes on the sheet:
uC pins: 7 11 28
~+26V
+34V
~-26V
-34V
INPUTS 2x5V ac 2x30V ac OUTPUTS 3V3 dc digital 5V dc digital 5V dc analog -5V dc analog 24V dc analog -24V dc analog

Board: 2 copper layers, 88 parts (0 on the bottom side), 58 nets, no tracks yet.

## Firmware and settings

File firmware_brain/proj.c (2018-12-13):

//
//  author:          Petre Rodan <2b4eda@subdimension.ro>
//  available from:  https://github.com/rodan/ampy
//  license:         GNU GPLv3

#include <stdio.h>
#include <string.h>

#include "proj.h"
#include "drivers/sys_messagebus.h"
#include "drivers/pmm.h"
#include "drivers/timer_a0.h"
#include "drivers/timer_a1.h"
#include "drivers/uart0.h"
#include "drivers/ir_remote.h"
#include "drivers/pga2311_helper.h"
#include "drivers/lm4780_helper.h"
#include "drivers/flash.h"
#include "drivers/port.h"
#include "drivers/rtc.h"
#include "ui.h"

#ifdef USE_UART
#include "interface/uart_fcts.h"
#endif

#ifdef USE_I2C
#include "interface/i2c_fcts.h"
  #ifdef HARDWARE_I2C
    #include "drivers/i2c.h"
  #else
    #include "serial_bitbang.h"
  #endif
#endif

int8_t ir_number;
uint8_t pga_id_cur = -1;

const uint8_t detect_port[DETECT_CHANNELS] = { BIT7, BIT1 };

#define SLOW_REFRESH_DELAY 56   // 56 ta0 overflows are 56*128s ~= 2hours
uint16_t tfr = SLOW_REFRESH_DELAY;   // time for display refresh

uint8_t d;
char muted[] = "muted";

void display_mixer_status(void)
{
    d = 0;
    tfr = timer_a0_ovf + SLOW_REFRESH_DELAY; // refresh once an hour
    timer_a0_delay_noblk_ccr1(_100ms);
}

static void timer_a0_ovf_irq(enum sys_message msg)
{
    if (timer_a0_ovf >= tfr) {
        if (timer_a0_ovf > 65535 - SLOW_REFRESH_DELAY) {
            return;
        }
        get_mixer_status();
        display_mixer_status();
    }
}

static void timer_a0_ccr1_irq(enum sys_message msg)
{
    switch (d) {
        case 0:
            snprintf(str_temp, TEMP_LEN, "1front     %3d %3d %s\n", s.v[0], s.v[1], mixer_get_mute_struct(1)?"":muted);
            break;
        case 1:
            snprintf(str_temp, TEMP_LEN, "2rear      %3d %3d %s\n", s.v[2], s.v[3], mixer_get_mute_struct(2)?"":muted);
            break;
        case 2:
            snprintf(str_temp, TEMP_LEN, "3line in   %3d %3d %s\n", s.v[4], s.v[5], mixer_get_mute_struct(3)?"":muted);
            break;
        case 3:
            snprintf(str_temp, TEMP_LEN, "4spdif     %3d %3d %s\n", s.v[6], s.v[7], mixer_get_mute_struct(4)?"":muted);
            break;
        case 4:
            snprintf(str_temp, TEMP_LEN, "5f-r pan   %3d %3d %s\n", s.v[8], s.v[9], mixer_get_mute_struct(5)?"":muted);
            break;
        case 5:
            snprintf(str_temp, TEMP_LEN, "6center    %3d     %s\n", s.v[10], mixer_get_mute_struct(6)?"":muted);
            break;
        case 6:
            snprintf(str_temp, TEMP_LEN, "7subwoofer %3d     %s\n", s.v[11], mixer_get_mute_struct(6)?"":muted);
            break;
        case 7:
            snprintf(str_temp, TEMP_LEN, "A\n");
            break;
        default:
            return;
    }

    d++;
    uart0_tx_str(str_temp, strlen(str_temp));
    //timer_a0_delay_noblk_ccr1(_500ms);
    timer_a0_delay_noblk_ccr1(_10ms);
}

static void parse_UI(enum sys_message msg)
{
    parse_user_input();

    uart0_p = 0;
    uart0_rx_enable = 1;
}

// edge detect based interrupt handler
static void port_trigger(enum sys_message msg)
{
    uint8_t i;

    // input_ed bit is HIGH if a HIGH->LOW transition happened
    // aka sound is detected

    for (i=0;i<DETECT_CHANNELS;i++) {
        if (ampy_get_detect(i+1) && (input_ed & detect_port[i])) {
            stat.count[i]=0;
            timer_a0_delay_noblk_ccr2(_50ms);
        }
    }

}

// time based interrupt request handler
static void port_parser(enum sys_message msg)
{
    uint8_t input_cur[DETECT_CHANNELS] = {LIVE, LIVE};
    uint8_t i;
    uint8_t smth_changed = 0;

    // port gets LOW if sound is detected

    if (P1IN & detect_port[0]) {
        input_cur[0] = MUTE;
    }

    if (P1IN & detect_port[1]) {
        input_cur[1] = MUTE;
    }
           
    for (i=0;i<DETECT_CHANNELS;i++) {
        if (ampy_get_detect(i+1) && (input_cur[i]!=stat.input_last[i])) {
            smth_changed = 1;
            stat.count[i]++;
            if ((stat.input_last[i] == MUTE) && (stat.count[i] > ON_DEBOUNCE)) {
                stat.count[i] = 0;
                ampy_set_status(i+1, LIVE);
                stat.input_last[i] = LIVE;
                //LED_ON;
                if (i == 0) {
                    UNMUTE_FRONT;
                } else if (i == 1) {
                    UNMUTE_REAR;
                }
            } else if ((stat.input_last[i] == LIVE) && (stat.count[i] > OFF_DEBOUNCE)) {
                stat.count[i] = 0;
                ampy_set_status(i+1, MUTE);
                stat.input_last[i] = MUTE;
                /*
                if ((ampy_get_status(1) == MUTE) && (ampy_get_status(2) == MUTE)) {
                    LED_OFF;
                }
                */
                if (i == 0) {
                    MUTE_FRONT;
                } else if (i == 1) {
                    MUTE_REAR;
                }
            }
        }
    }

    if (smth_changed) {
        timer_a0_delay_noblk_ccr2(_50ms);
    } else {
        timer_a0_delay_noblk_ccr2(_1s);
    }
}

int main(void)
{
    main_init();
    rtca_init();
    timer_a0_init();
    ir_init();
    uart0_init();

#ifdef HARDWARE_I2C
    i2c_init();
#endif

    // refresh the volume levels on the display once in a while
    //sys_messagebus_register(&timer_a0_ovf_irq, SYS_MSG_TIMER0_IFG);
    //sys_messagebus_register(&timer_a0_ccr1_irq, SYS_MSG_TIMER0_CCR1);

    sys_messagebus_register(&port_parser, SYS_MSG_TIMER0_CCR2);
    sys_messagebus_register(&port_trigger, SYS_MSG_PORT_TRIG);
    sys_messagebus_register(&parse_UI, SYS_MSG_UART0_RX);

    // the mixer gets initialized after ~1s
    timer_a0_delay_ccr4(_1500ms);
    get_mixer_status();

    settings_init(FLASH_ADDR);
    settings_apply();

    while (1) {
        _BIS_SR(LPM3_bits + GIE);
#ifdef USE_WATCHDOG
        WDTCTL = (WDTCTL & 0xff) | WDTPW | WDTCNTCL;
#endif
        check_events();
        check_ir();
    }
}

void main_init(void)
{

    // watchdog triggers after 25sec when not cleared
#ifdef USE_WATCHDOG
    WDTCTL = WDTPW + WDTIS__512K + WDTSSEL__ACLK + WDTCNTCL;
#else
    WDTCTL = WDTPW + WDTHOLD;
#endif
    SetVCore(3);

    P1SEL = 0x0;
    P1DIR = 0x1;
    P1OUT = 0x0;

    P2SEL = 0x0;
    P2DIR = 0xff;
    P2OUT = 0x0;

    P3SEL = 0x0;
    P3DIR = 0xff;
    P3OUT = 0x0;

    P5SEL |= BIT0 + BIT1;

    PJDIR = 0xff;
    PJOUT = 0x00;

    // port mappings
    PMAPPWD = 0x02D52;
    // hardware UART
    P1MAP5 = PM_UCA0TXD;
    P1MAP6 = PM_UCA0RXD;
#ifdef USE_I2C
  #ifdef HARDWARE_I2C
    // set up i2c port mapping
    P1MAP2 = PM_UCB0SCL;
    P1MAP3 = PM_UCB0SDA;
    P1SEL |= BIT2 + BIT3;
  #endif
#endif
    PMAPPWD = 0;

    P1SEL |= BIT5 + BIT6;

}

void check_events(void)
{
    struct sys_messagebus *p = messagebus;
    enum sys_message msg = 0;

    // drivers/timer_a0
    if (timer_a0_last_event) {
        msg |= timer_a0_last_event;
        timer_a0_last_event = 0;
    }
    // drivers/timer1a
    if (timer_a1_last_event) {
        msg |= timer_a1_last_event << 7;
        timer_a1_last_event = 0;
    }
    // drivers/uart0
    if (uart0_last_event == UART0_EV_RX) {
        msg |= SYS_MSG_UART0_RX;
        uart0_last_event = 0;
    }
    // drivers/port
    if (port_last_event) {
        msg |= SYS_MSG_PORT_TRIG;
        port_last_event = 0;
    }

    while (p) {
        // notify listener if he registered for any of these messages
        if (msg & p->listens) {
            p->fn(msg);
        }
        p = p->next;
    }
}

void check_ir(void)
{
    if (ir_decode(&results)) {

        ir_number = -1;

        switch (results.value) {
            // RC5 codes
        case 1:                // 1
            ir_number = 1;
            break;
        case 2:                // 2
            ir_number = 2;
            break;
        case 3:                // 3
            ir_number = 3;
            break;
        case 4:                // 4
            ir_number = 4;
            break;
        case 5:                // 5
            ir_number = 5;
            break;
        case 6:                // 6
            ir_number = 6;
            break;
        case 7:                // 7
            ir_number = 7;
            break;
        case 8:                // 8
            ir_number = 8;
            break;
        case 9:                // 9
            ir_number = 9;
            break;
        case 0:                // 0
            ir_number = 0;
            break;
/*
        case 10: // 10
            ir_number = 10;
            break;
        case 12:               // power
            // wake up from pwr_down
            break;
        case 56:               // AV
            in_number = 0;
            break;
        case 36: // red
          break;
        case 35: // green
          break;
        case 14: // yellow
          break;
        case 50: // zoom
            break;
*/
        case 39: // sub
            display_mixer_status();
            break;
/*
        case 44: // slow
            break;
*/
        case 60: // repeat
            get_mixer_status();
            break;
/*
        case 15: // disp
            break;
        case 38: // sleep
            break;
        case 32: // up
            break;
        case 33: // down
            break;
        case 16: // right
            break;
        case 17: // left
            break;
        case 59: // ok
            break;
        case 34: // back
            break;
        case 19: // exit
            break;
        case 18: // menu
            break;
*/
        case 13:
        case 0x290:            // mute
            mixer_send_funct(pga_id_cur, FCT_T_MUTE, 0, 0);
            tfr = timer_a0_ovf + 1;
            break;
        case 16:
        case 0x490:            // vol+
            mixer_send_funct(pga_id_cur, FCT_V_INC, VOL_STEP, VOL_STEP);
            tfr = timer_a0_ovf + 1;
            break;
        case 17:
        case 0xc90:            // vol-
            mixer_send_funct(pga_id_cur, FCT_V_DEC, VOL_STEP, VOL_STEP);
            tfr = timer_a0_ovf + 1;
            break;
        case 28:
        case 0x90:             // ch+
            mixer_send_funct(pga_id_cur, FCT_V_INC, VOL_BIG_STEP, VOL_BIG_STEP);
            tfr = timer_a0_ovf + 1;
            break;
        case 29:
        case 0x890:            // ch-
            mixer_send_funct(pga_id_cur, FCT_V_DEC, VOL_BIG_STEP, VOL_BIG_STEP);
            tfr = timer_a0_ovf + 1;
            break;
        case 36:               // record
            save_presets(pga_id_cur); 
            break;
/*
        case 54:
        case 0xa90:            // stop
            break;
*/
        case 14:               // play
            load_presets(pga_id_cur);
            tfr = timer_a0_ovf + 1;
            break;
/*
        case 31:               // pause
            break;
        case 35:
        case 0xa50:            // rew, AV/TV
            break;
        case : // fwd
            break;
*/
        default:
            break;
        }                       // switch

        if (ir_number > 0) {
            pga_id_cur = ir_number;
        }

        //snprintf(str_temp, TEMP_LEN, "%ld\r\n", results.value);
        //uart0_tx_str(str_temp, strlen(str_temp));

        ir_resume();            // Receive the next value
    }
}

/*
uint8_t str_to_uint16(char *str, uint16_t * out, const uint8_t seek,
                      const uint8_t len, const uint16_t min, const uint16_t max)
{
    uint16_t val = 0, pow = 1;
    uint8_t i;

    // pow() is missing in gcc, so we improvise
    for (i = 0; i < len - 1; i++) {
        pow *= 10;
    }
    for (i = 0; i < len; i++) {
        if ((str[seek + i] > 47) && (str[seek + i] < 58)) {
            val += (str[seek + i] - 48) * pow;
        }
        pow /= 10;
    }
    if ((val >= min) && (val <= max)) {
        *out = val;
    } else {
        snprintf(str_temp, TEMP_LEN, "\e[31;1merr\e[0m specify an int between %u-%u\r\n",
                min, max);
        uart0_tx_str(str_temp, strlen(str_temp));
        return 0;
    }
    return 1;
}
*/

void settings_init(uint8_t * addr)
{
    uint8_t *src_p, *dst_p;
    //uint8_t *ptr;
    //uint8_t right, left;
    uint8_t i;

    src_p = addr;
    dst_p = (uint8_t *) & a;
    if ((*src_p) != A_VER) {
        src_p = (uint8_t *) & defaults;
    }
    for (i = 0; i < sizeof(a); i++) {
        *dst_p++ = *src_p++;
    }
}

void settings_apply(void)
{
#ifdef SND_DETECT

    uint8_t i;
    uint8_t tmp;

	// IRQ triggers on a hi-low transition
	P1IES |= detect_port[0] + detect_port[1];
	P1IFG &= ~(detect_port[0] + detect_port[1]);
	P1IE &= ~(detect_port[0] + detect_port[1]);

    for (i=0;i<DETECT_CHANNELS;i++) {
        if (ampy_get_detect(i+1)) {
        	P1IE |= detect_port[i];
            ampy_set_status(i+1, MUTE);
            if (i == 0) {
                MUTE_FRONT;
            } else if (i == 1) {
                MUTE_REAR;
            }
        } else {
            tmp = ampy_get_mute(i+1);
            ampy_set_status(i+1, tmp);
            if (tmp == MUTE) {
                if (i == 0) {
                    MUTE_FRONT;
                } else if (i == 1) {
                    MUTE_REAR;
                }
            } else {
                if (i == 0) {
                    UNMUTE_FRONT;
                } else if (i == 1) {
                    UNMUTE_REAR;
                }
            }
        }
        stat.input_last[i] = MUTE;
    }
#endif

    amp_output_set();
}

// check if there is any amp with all inputs muted
void amp_output_set(void)
{
    uint32_t tvol_front, tvol_rear, tvol_in, tvol_pan;

    tvol_front = mixer_get_mute_struct(1)*(mixer_get_vol_struct(1, CH_RIGHT) + mixer_get_vol_struct(1, CH_LEFT));
    tvol_rear  = mixer_get_mute_struct(2)*(mixer_get_vol_struct(2, CH_RIGHT) + mixer_get_vol_struct(2, CH_LEFT));
    tvol_in    = mixer_get_mute_struct(3)*(mixer_get_vol_struct(3, CH_RIGHT) + mixer_get_vol_struct(3, CH_LEFT));
    tvol_in   += mixer_get_mute_struct(4)*(mixer_get_vol_struct(4, CH_RIGHT) + mixer_get_vol_struct(4, CH_LEFT));
    tvol_pan   = mixer_get_mute_struct(5)*(mixer_get_vol_struct(5, CH_RIGHT) + mixer_get_vol_struct(5, CH_LEFT));

    //snprintf(str_temp, TEMP_LEN, "am %lu %lu %lu %lu %d %d ", tvol_front, tvol_rear, tvol_in, tvol_pan, mixer_get_mute_struct(4), mixer_get_vol_struct(4, CH_RIGHT));
    //uart0_tx_str(str_temp, strlen(str_temp));

    if (tvol_front + tvol_in) {
        UNMUTE_FRONT;
        ampy_set_status(1, LIVE);
    } else {
        MUTE_FRONT;
        ampy_set_status(1, MUTE);
    }


    if (tvol_rear + (tvol_in * tvol_pan)) {
        UNMUTE_REAR;
        ampy_set_status(2, LIVE);
    } else {
        MUTE_REAR;
        ampy_set_status(2, MUTE);
    }

    if ((ampy_get_status(1) == MUTE) && (ampy_get_status(2) == MUTE)) {
        LED_OFF;
    } else {
        LED_ON;
    }

}

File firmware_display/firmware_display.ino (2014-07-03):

#include <inttypes.h>
#include <ctype.h>
#include <SPI.h>
#include <SD.h>
#include "EPD.h"
#include "S5813A.h"
#include "EReader.h"

// the eink related libraries are available from
// https://github.com/wyolum/EPD

int cmd;
char buffer[50];

void setup()
{
    Serial.begin(9600);
    ereader.setup(EPD_2_7);
}

void loop()
{

    if (Serial.available() > 0) {
        memset(buffer, 0, sizeof(buffer));
        cmd = Serial.read();
        Serial.readBytesUntil(0x0a, buffer, 50);
        ereader.spi_attach();
        if (cmd == '1')
            ereader.put_ascii(25, 20, buffer, true);
        else if (cmd == '2')
            ereader.put_ascii(25, 36, buffer, true);
        else if (cmd == '3')
            ereader.put_ascii(25, 52, buffer, true);
        else if (cmd == '4')
            ereader.put_ascii(25, 68, buffer, true);
        else if (cmd == '5')
            ereader.put_ascii(25, 84, buffer, true);
        else if (cmd == '6')
            ereader.put_ascii(25, 100, buffer, true);
        else if (cmd == '7')
            ereader.put_ascii(25, 116, buffer, true);
        else if (cmd == '8')
            ereader.put_ascii(25, 132, buffer, true);
        else if (cmd == '9')
            ereader.put_ascii(25, 148, buffer, true);
        else if (cmd == 'A') {
            ereader.show();
            ereader.spi_detach();       //To avoid screen washout.
        }
    }

}

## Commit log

2014-02-09 add png
    [mixer.brd, mixer.sch]
2014-02-09 power tweaked
    [mixer.brd, mixer.sch]
2014-02-09 add msp
    [mixer.brd, mixer.sch]
2014-02-11 add power module
    [power.brd, power.sch]
2014-02-15 change C footprints
    [mixer.brd, mixer.sch, power.brd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]
2014-02-15 change input filters
    [mixer.brd, mixer.sch]
2014-02-15 add jumper for pan input
    [mixer.brd, mixer.sch]
2014-02-15 change input filters - agin
    [mixer.brd, mixer.sch]
2014-02-16 started routing
    [mixer.brd, mixer.sch]
2014-04-19 use 7905
    [power.brd, power.sch]
2014-04-28 done routing the mixer
    [mixer.brd, mixer.sch]
2014-04-28 add amp
    [amp.brd, amp.sch]
2014-04-28 amp update
    [amp.brd, amp.sch]
2014-05-02 amplifier schematic
    [amp.brd, amp.sch]
2014-05-12 mosfets purchased
    [mixer.brd, mixer.sch, power.brd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]
2014-05-13 amp routed
    [amp.brd, amp.sch]
2014-05-14 add low voltage power source board
    [power.brd, power.sch, power_pre.brd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]
2014-05-15 add amp source board
    [power_amp.brd, power_amp.sch]
2014-05-20 sent to manufacture
    [amp.brd, amp.sch, mixer.brd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]
2014-06-02 tweak filters
    [mixer.brd, mixer.sch, power_pre.brd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]
2014-06-04 small tweaks
    [mixer.brd, mixer.sch]
2014-06-08 board rev 1.1
    [amp.brd, amp.sch, mixer.brd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]
2014-06-08 change +5v bridge rectifier in power_pre
    [power_pre.brd, power_pre.sch]
2014-06-15 add i2c and uart interfaces
2014-07-03 add pic link
    [amp.brd]
2014-12-19 new power amp
    [amp_lm4780.brd, amp_lm4780.sch, mixer.brd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]
2014-12-20 switch to i2c bitbang, implelent clock stretching
2015-01-22 fix gnd_c in amp_lm4780
    [amp_lm4780.brd, amp_lm4780.sch]
2015-01-23 add buffer to snd detect circuit
    [amp_lm4780.brd, amp_lm4780.sch]
2015-01-27 redesign snd_detect circuit layout
    [amp_lm4780.brd, amp_lm4780.sch]
2015-01-28 snd_detect cleanup
    [amp_lm4780.brd, amp_lm4780.sch]
2015-01-29 snd_detect revisited
    [amp_lm4780.brd, amp_lm4780.sch]
2015-02-12 add temperature sensing
2015-02-16 add temperature reading inside the mixer board
2015-02-17 add debug window into ncurses cli
    [amp_lm4780.brd, amp_lm4780.sch, power_pre.brd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]
2015-03-28 power down amps when there is no active channel driving them

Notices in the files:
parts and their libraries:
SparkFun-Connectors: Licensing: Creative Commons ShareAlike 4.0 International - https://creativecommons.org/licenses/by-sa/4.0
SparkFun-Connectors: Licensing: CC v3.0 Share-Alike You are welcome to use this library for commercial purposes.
